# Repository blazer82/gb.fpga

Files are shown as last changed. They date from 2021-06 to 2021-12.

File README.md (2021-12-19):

[](https://github.com/blazer82/gb.fpga/actions?workflow=verilator-lint)

# FPGAMB0 - FPGA-based Handheld Console

This repository contains the PCB design files as well as the HDL sources for an FPGA-based handheld console that plays games from Gameboy cartridges.

## Demo (GIF)

Demo

## Testbenches

Testbench files can be run and analyzed using _iverilog_ and _GTKWave_:

```
iverilog -o main src/hdl/ascii_encoder_tb.v && vvp main -lxt2 && open dump.lx2
```

[verilator-lint-badge]: https://github.com/blazer82/gb.fpga/workflows/verilator-lint/badge.svg

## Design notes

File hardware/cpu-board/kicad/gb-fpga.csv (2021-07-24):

Cartridge-32pin | J
Pin | Name | Type | Side | Unit | Style | Hidden
1 | VCC | pwr | left | 1
2 | CLK | in | left | 1
3 | ~WR~ | in | left | 1
4 | ~RD~ | in | left | 1
5 | ~CS~ | in | left | 1
6 | A0 | in | left | 1
7 | A1 | in | left | 1
8 | A2 | in | left | 1
9 | A3 | in | left | 1
10 | A4 | in | left | 1
11 | A5 | in | left | 1
12 | A6 | in | left | 1
13 | A7 | in | left | 1
14 | A8 | in | left | 1
15 | A9 | in | left | 1
16 | A10 | in | left | 1
17 | A11 | in | left | 1
18 | A12 | in | left | 1
19 | A13 | in | left | 1
20 | A14 | in | left | 1
21 | A15 | in | left | 1
22 | D0 | passive | left | 1
23 | D1 | passive | left | 1
24 | D2 | passive | left | 1
25 | D3 | passive | left | 1
26 | D4 | passive | left | 1
27 | D5 | passive | left | 1
28 | D6 | passive | left | 1
29 | D7 | passive | left | 1
30 | ~RST~ | in | left | 1
31 | NC | NC | left | 1
32 | GND | pwr | left | 1
R_POT_Dual | RV
Pin | Name | Type | Side | Unit | Style | Hidden
1 | 1 | passive | left | 1
2 | 2 | passive | left | 1
3 | 3 | passive | top | 1
4 | 4 | passive | top | 1
5 | 5 | passive | right | 1
5 | 5 | passive | right | 1
Switch | SW
Pin | Name | Type | Side | Unit | Style | Hidden
1 | ~ | passive | right | 1
2 | ~ | passive | left | 1
3 | ~ | passive | right | 1
4 | GND | pwr | left | 1
TXS0108E | U
Pin | Name | Type | Side | Unit | Style | Hidden
1 | A1 | bidir | left | 1
2 | VCCA | pwr | left | 1
3 | A2 | bidir | left | 1
4 | A3 | bidir | left | 1
5 | A4 | bidir | left | 1
6 | A5 | bidir | left | 1
7 | A6 | bidir | left | 1
8 | A7 | bidir | left | 1
9 | A8 | bidir | left | 1
10 | OE | in | left | 1
11 | GND | pwr | right | 1
12 | B8 | bidir | right | 1
13 | B7 | bidir | right | 1
14 | B6 | bidir | right | 1
15 | B5 | bidir | right | 1
16 | B4 | bidir | right | 1
17 | B3 | bidir | right | 1
18 | B2 | bidir | right | 1
19 | VCCB | pwr | right | 1
20 | B1 | bidir | right | 1
xc7s25ftgb196 | U
Pin | Name | Type | Side | Unit | Style | Hidden
A7 | TCK_0 | in | right | 1
A8 | CCLK_0 | in | left | 1
A10 | IO_L3N_T0_DQS_EMCCLK_14 | bidir | right | 1
B10 | IO_L3P_T0_DQS_PUDC_B_14 | bidir | right | 1
B11 | IO_L1P_T0_D00_MOSI_14 | bidir | right | 1
B12 | IO_L1N_T0_D01_DIN_14 | bidir | right | 1
C10 | IO_L2N_T0_D03_14 | bidir | right | 1
C11 | IO_L6P_T0_FCS_B_14 | bidir | right | 1
D10 | IO_L2P_T0_D02_14 | bidir | right | 1
G7 | VREFN_0 | in | left | 1
G8 | VP_0 | in | left | 1
H7 | VN_0 | in | left | 1
H8 | VREFP_0 | in | left | 1
J7 | DXN_0 | passive | left | 1
J8 | DXP_0 | passive | left | 1
L7 | PROGRAM_B_0 | in | left | 1
M6 | TMS_0 | in | right | 1
M7 | M0_0 | in | left | 1
M8 | M1_0 | in | left | 1
M9 | M2_0 | in | left | 1
N7 | CFGBVS_0 | in | left | 1
P6 | TDO_0 | out | right | 1
P7 | TDI_0 | in | right | 1
P8 | INIT_B_0 | in | left | 1
P9 | DONE_0 | out | left | 1
A12 | IO_L4P_T0_D04_14 | bidir | left | 2
A13 | IO_L4N_T0_D05_14 | bidir | left | 2
B13 | IO_L5P_T0_D06_14 | bidir | left | 2
B14 | IO_L5N_T0_D07_14 | bidir | left | 2
C12 | IO_L6N_T0_D08_VREF_14 | bidir | left | 2
C14 | IO_L11N_T1_SRCC_14 | bidir | left | 2
D12 | IO_L8P_T1_D11_14 | bidir | left | 2
D13 | IO_L8N_T1_D12_14 | bidir | left | 2
D14 | IO_L11P_T1_SRCC_14 | bidir | left | 2
E11 | IO_0_14 | bidir | left | 2
E12 | IO_L7N_T1_D10_14 | bidir | left | 2
E13 | IO_L10N_T1_D15_14 | bidir | left | 2
F11 | IO_L12N_T1_MRCC_14 | bidir | left | 2
F12 | IO_L7P_T1_D09_14 | bidir | left | 2
F13 | IO_L10P_T1_D14_14 | bidir | left | 2
F14 | IO_L9N_T1_DQS_D13_14 | bidir | left | 2
G11 | IO_L12P_T1_MRCC_14 | bidir | left | 2
G14 | IO_L9P_T1_DQS_14 | bidir | left | 2
H11 | IO_L13P_T2_MRCC_14 | bidir | left | 2
H12 | IO_L13N_T2_MRCC_14 | bidir | left | 2
H13 | IO_L14P_T2_SRCC_14 | bidir | left | 2
H14 | IO_L14N_T2_SRCC_14 | bidir | left | 2
J11 | IO_L17P_T2_D30_14 | bidir | left | 2
J12 | IO_L17N_T2_D29_14 | bidir | left | 2
J13 | IO_L18P_T2_D28_14 | bidir | left | 2
J14 | IO_L18N_T2_D27_14 | bidir | left | 2
K11 | IO_L19P_T3_D26_14 | bidir | left | 2
K12 | IO_L19N_T3_D25_VREF_14 | bidir | left | 2
L12 | IO_L16P_T2_CSI_B_14 | bidir | left | 2
L13 | IO_L16N_T2_D31_14 | bidir | left | 2
L14 | IO_L15N_T2_DQS_DOUT_CSO_B_14 | bidir | left | 2
M10 | IO_25_14 | bidir | left | 2
M11 | IO_L20P_T3_D24_14 | bidir | left | 2
M12 | IO_L20N_T3_D23_14 | bidir | left | 2
M13 | IO_L15P_T2_DQS_RDWR_B_14 | bidir | left | 2
M14 | IO_L21N_T3_DQS_D22_14 | bidir | left | 2
N10 | IO_L23P_T3_D19_14 | bidir | left | 2
N11 | IO_L23N_T3_D18_14 | bidir | left | 2
N14 | IO_L21P_T3_DQS_14 | bidir | left | 2
P10 | IO_L24P_T3_D17_14 | bidir | left | 2
P11 | IO_L24N_T3_D16_14 | bidir | left | 2
P12 | IO_L22P_T3_D21_14 | bidir | left | 2
P13 | IO_L22N_T3_D20_14 | bidir | left | 2
A2 | IO_L3N_T0_DQS_34 | bidir | left | 3
A3 | IO_L2N_T0_34 | bidir | left | 3
A4 | IO_L2P_T0_34 | bidir | left | 3
A5 | IO_L4N_T0_34 | bidir | left | 3
B1 | IO_L5N_T0_34 | bidir | left | 3
B2 | IO_L5P_T0_34 | bidir | left | 3
B3 | IO_L3P_T0_DQS_34 | bidir | left | 3
B5 | IO_L4P_T0_34 | bidir | left | 3
B6 | IO_0_34 | bidir | left | 3
C1 | IO_L11N_T1_SRCC_34 | bidir | left | 3
C3 | IO_L1N_T0_34 | bidir | left | 3
C4 | IO_L6N_T0_VREF_34 | bidir | left | 3
C5 | IO_L6P_T0_34 | bidir | left | 3
D1 | IO_L11P_T1_SRCC_34 | bidir | left | 3
D2 | IO_L10N_T1_34 | bidir | left | 3
D3 | IO_L1P_T0_34 | bidir | left | 3
D4 | IO_L7N_T1_34 | bidir | left | 3
E2 | IO_L10P_T1_34 | bidir | left | 3
E4 | IO_L7P_T1_34 | bidir | left | 3
F1 | IO_L9N_T1_DQS_34 | bidir | left | 3
F2 | IO_L8N_T1_34 | bidir | left | 3
F3 | IO_L8P_T1_34 | bidir | left | 3
F4 | IO_L12N_T1_MRCC_34 | bidir | left | 3
G1 | IO_L9P_T1_DQS_34 | bidir | left | 3
G4 | IO_L12P_T1_MRCC_34 | bidir | left | 3
H1 | IO_L14N_T2_SRCC_34 | bidir | left | 3
H2 | IO_L14P_T2_SRCC_34 | bidir | left | 3
H3 | IO_L13N_T2_MRCC_34 | bidir | left | 3
H4 | IO_L13P_T2_MRCC_34 | bidir | left | 3
J1 | IO_L15N_T2_DQS_34 | bidir | left | 3
J2 | IO_L15P_T2_DQS_34 | bidir | left | 3
J3 | IO_L17N_T2_34 | bidir | left | 3
J4 | IO_L17P_T2_34 | bidir | left | 3
K3 | IO_L16N_T2_34 | bidir | left | 3
K4 | IO_L16P_T2_34 | bidir | left | 3
L1 | IO_L18N_T2_34 | bidir | left | 3
L2 | IO_L22N_T3_34 | bidir | left | 3
L3 | IO_L22P_T3_34 | bidir | left | 3
L5 | IO_25_34 | bidir | left | 3
M1 | IO_L18P_T2_34 | bidir | left | 3
M2 | IO_L19N_T3_VREF_34 | bidir | left | 3
M3 | IO_L19P_T3_34 | bidir | left | 3
M4 | IO_L23N_T3_34 | bidir | left | 3
M5 | IO_L23P_T3_34 | bidir | left | 3
N1 | IO_L20N_T3_34 | bidir | left | 3
N4 | IO_L24N_T3_34 | bidir | left | 3
P2 | IO_L20P_T3_34 | bidir | left | 3
P3 | IO_L21N_T3_DQS_34 | bidir | left | 3
P4 | IO_L21P_T3_DQS_34 | bidir | left | 3
P5 | IO_L24P_T3_34 | bidir | left | 3
A1 | GND[50] | pwr | right | 4
A6 | GND[50] | pwr | right | 4
A9 | GND[50] | pwr | right | 4
A11 | GND[50] | pwr | right | 4
A14 | GND[50] | pwr | right | 4
B4 | GND[50] | pwr | right | 4
B7 | GND[50] | pwr | right | 4
B8 | VCCBATT_0 | pwr | left | 4
B9 | GND[50] | pwr | right | 4
C2 | GND[50] | pwr | right | 4
C6 | GND[50] | pwr | right | 4
C7 | GND[50] | pwr | right | 4
C8 | GND[50] | pwr | right | 4
C9 | GND[50] | pwr | right | 4
C13 | GND[50] | pwr | right | 4
D5 | GND[50] | pwr | right | 4
D6 | VCCINT[10] | pwr | left | 4
D7 | GND[50] | pwr | right | 4
D8 | VCCINT[10] | pwr | left | 4
D9 | GND[50] | pwr | right | 4
D11 | GND[50] | pwr | right | 4
E1 | GND[50] | pwr | right | 4
E3 | GND[50] | pwr | right | 4
E5 | VCCBRAM[3] | pwr | left | 4
E6 | GND[50] | pwr | right | 4
E7 | VCCINT[10] | pwr | left | 4
E8 | GND[50] | pwr | right | 4
E9 | VCCINT[10] | pwr | left | 4
E10 | GND[50] | pwr | right | 4
E14 | GND[50] | pwr | right | 4
F5 | GND[50] | pwr | right | 4
F6 | VCCINT[10] | pwr | left | 4
F7 | GNDADC_0 | pwr | right | 4
F8 | VCCADC_0 | pwr | left | 4
F9 | GND[50] | pwr | right | 4
F10 | VCCAUX[4] | pwr | left | 4
G2 | VCCO_34[3] | pwr | left | 4
G3 | GND[50] | pwr | right | 4
G5 | VCCBRAM[3] | pwr | left | 4
G6 | GND[50] | pwr | right | 4
G9 | VCCINT[10] | pwr | left | 4
G10 | GND[50] | pwr | right | 4
G12 | GND[50] | pwr | right | 4
G13 | VCCO_14[3] | pwr | left | 4
H5 | GND[50] | pwr | right | 4
H6 | VCCINT[10] | pwr | left | 4
H9 | GND[50] | pwr | right | 4
H10 | VCCAUX[4] | pwr | left | 4
J5 | VCCBRAM[3] | pwr | left | 4
J6 | GND[50] | pwr | right | 4
J9 | VCCINT[10] | pwr | left | 4
J10 | GND[50] | pwr | right | 4
K1 | GND[50] | pwr | right | 4
K2 | VCCO_34[3] | pwr | left | 4
K5 | GND[50] | pwr | right | 4
K6 | VCCINT[10] | pwr | left | 4
K7 | GND[50] | pwr | right | 4
K8 | VCCINT[10] | pwr | left | 4
K9 | GND[50] | pwr | right | 4
K10 | VCCAUX[4] | pwr | left | 4
K13 | VCCO_14[3] | pwr | left | 4
K14 | GND[50] | pwr | right | 4
L4 | GND[50] | pwr | right | 4
L6 | GND[50] | pwr | right | 4
L8 | GND[50] | pwr | right | 4
L9 | VCCAUX[4] | pwr | left | 4
L10 | GND[50] | pwr | right | 4
L11 | GND[50] | pwr | right | 4
N2 | VCCO_34[3] | pwr | left | 4
N3 | GND[50] | pwr | right | 4
N5 | GND[50] | pwr | right | 4
N6 | VCCO_0[2] | pwr | left | 4
N8 | VCCO_0[2] | pwr | left | 4
N9 | GND[50] | pwr | right | 4
N12 | GND[50] | pwr | right | 4
N13 | VCCO_14[3] | pwr | left | 4
P1 | GND[50] | pwr | right | 4
P14 | GND[50] | pwr | right | 4

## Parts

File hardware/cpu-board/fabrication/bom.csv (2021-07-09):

Designator | Value | Package/Footprint | Mfg Part # | Qty
C1, C50, C51, C52, C53, C54, C55, C56, C57, C59, C61, C62, C63, C64, C65, C66, C67, C68 | 100nF | 0402 | CL05B104KO5NNNC | 18
C1 | 100nF | 0402 | CL05B104KO5NNNC | 1
C50 | 100nF | 0402 | CL05B104KO5NNNC | 1
C51 | 100nF | 0402 | CL05B104KO5NNNC | 1
C52 | 100nF | 0402 | CL05B104KO5NNNC | 1
C53 | 100nF | 0402 | CL05B104KO5NNNC | 1
C54 | 100nF | 0402 | CL05B104KO5NNNC | 1
C55 | 100nF | 0402 | CL05B104KO5NNNC | 1
C56 | 100nF | 0402 | CL05B104KO5NNNC | 1
C57 | 100nF | 0402 | CL05B104KO5NNNC | 1
C59 | 100nF | 0402 | CL05B104KO5NNNC | 1
C61 | 100nF | 0402 | CL05B104KO5NNNC | 1
C62 | 100nF | 0402 | CL05B104KO5NNNC | 1
C63 | 100nF | 0402 | CL05B104KO5NNNC | 1
C64 | 100nF | 0402 | CL05B104KO5NNNC | 1
C65 | 100nF | 0402 | CL05B104KO5NNNC | 1
C66 | 100nF | 0402 | CL05B104KO5NNNC | 1
C67 | 100nF | 0402 | CL05B104KO5NNNC | 1
C68 | 100nF | 0402 | CL05B104KO5NNNC | 1
C2 | 10nF | 0402 | CL05B103KB5NNNC | 1
C3 | 470nF | 0402 | CL05A474KP5NNNC | 1
C4, C6, C8 | 20pF | 0402 | CL05C220JB5NNNC | 3
C5, C11 | 22µF | 0402 | GRM155R60J226ME11D | 2
C7, C9, C10 | 10µF | 0402 | CL05A106MP5NUNC | 3
C12 | 1µF | 0402 | CL05A105KO5NNNC | 1
C14, C18 | 47µF | 0603 | CL10A476MQ8QRNC | 2
C21, C27, C34, C41 | 100µF | 1206 | GRM31CR61A107ME05L | 4
C15, C19, C22, C23, C28, C29, C35, C36, C42, C43 | 4.7µF | 0201 | GRM035R60J475ME15D | 10
C16, C17, C20, C24, C25, C26, C30, C31, C32, C33, C37, C38, C39, C40, C44, C45, C46, C47 | 470nF | 0201 | GRM033R60J474KE90D | 18
C48, C49 | 4.7nF | 0402 | CL05B472KA5NNNC | 2
C13, C58, C60 | 4.7µF | 0402 | CL05A475KP5NRNC | 3
D1 | DONE | 0402 | NCD0402G1 | 1
D2 | PMEG2020EJ | SOD-323 | PMEG2020EJF | 1
D3 | CHRG | 0402 | NCD0402B1 | 1
J1 | USB_C_Receptacle_USB2.0 |  | U262-161N-4BVC11 | 1
J5 | Conn_02x25_Counter_Clockwise |  | FH12-50S-0.5SH(55) | 1
L1 | 1.5µH | 0402 | SDFL1005Q1R5KTF | 1
L2, L4 | 3.3µH | 0402 | SDFL1005Q3R3KTF | 2
L3 | 2.2µH | 0402 | SDFL1005Q2R2KTF | 1
L5 | 10µH | 0603 | SDFL1608S100KTF | 1
L6, L7 | 600R/0.5A | 0402 | BLM15AX601SN1D | 2
Q1 | MBT3904DW1 | SOT-363 | MBT3904DW1T1H | 1
R1, R5, R6, R7, R16, R17 | 4.7k | 0402 | RC0402JR-074K7L | 6
R2, R3 | 1.8k | 0402 | RC0402JR-071K8L | 2
R4, R15, R31, R35, R36 | 1k | 0402 | RC0402JR-071KL | 5
R8, R9, R32 | 200Ω | 0402 | AC0402JR-07200RL | 3
R10, R11, R12, R13, R26, R28 | 10k | 0402 | RC0402JR-0710KL | 6
R14 | 12k | 0402 | RC0402FR-0712KL | 1
R18, R27 | 3k | 0402 | RC0402FR-073KL | 2
R19 | 2k | 0402 | RC0402FR-072KL | 1
R20, R29, R30 | 30k | 0402 | AF0402FR-0730KL | 3
R21, R23 | 120k | 0402 | RC0402FR-07120KL | 2
R22 | 150k | 0402 | RC0402FR-07150KL | 1
R24, R34 | 180k | 0402 | RC0402FR-07180KL | 2
R25 | 57.6k | 0402 | RC0402FR-0757K6L | 1
R33 | 953k | 0402 | RC0402FR-07953KL | 1
U1 | xc7s25ftgb196 |  | XC7S25-1FTGB196C | 1
U2 | MX25R3235FZBxx1 | USON-8 | MX25L3233FZBI-08Q | 1
U3 | FT2232HQ | QFN-64 | FT2232HQ-REEL | 1
U4 | LTC3555 | QFN-28 | LTC3555IUFD-1#PBF | 1
U5 | TLV61046ADB | SOT-23-6 | TLV61046ADBVR | 1
U6, U7, U8, U9 | TXS0108E | TSSOP-20 | TXS0108EPWR | 4
X1 | SG-8002JA |  | CB3LV-3C-12M000000 | 1

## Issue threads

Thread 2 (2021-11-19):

Issue with the 12V rail

blazer82, 2021-11-19:
The 12V rail seems to be underpowered to provide proper power to the audio/video system. This is very noticeable when turning up the audio volume.

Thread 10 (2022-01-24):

Interest in PCB Design / Layout

32teeth, 2022-01-24:
# Hi
> Introduction

I created the Gameboy Pocket versions for
* [Gaboze Pocaio](https://github.com/Gaboze-Pocaio/Round-2) (Raspberry Pi)
* [Retro ESP32](https://github.com/retro-esp32/RetroESP32)

I've been looking at the next Gameboy Pocket emulation, and came across your FPGA project

blazer82, 2022-02-11:
Hi and sorry for the late reply. The PCB Design files are in this repository inside the hardware folder.

32teeth, 2022-06-24:
Hardware is [here](https://github.com/retro-esp32/RetroESP32-Hardware)

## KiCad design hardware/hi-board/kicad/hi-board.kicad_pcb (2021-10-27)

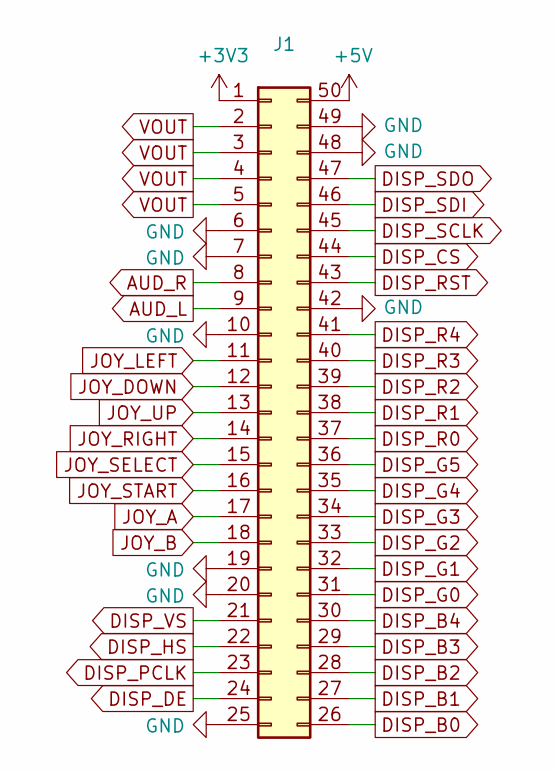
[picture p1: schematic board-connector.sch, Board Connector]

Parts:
J1: Conn_02x25_Counter_Clockwise; Hirose_FH12-50S-0.5SH_1x50-1MP_P0.50mm_Horizontal

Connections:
unnamed: J1.2, J1.3, J1.4, J1.5
unnamed: J1.6, J1.7, J1.10, J1.19, J1.20, J1.25, J1.42, J1.48, J1.49

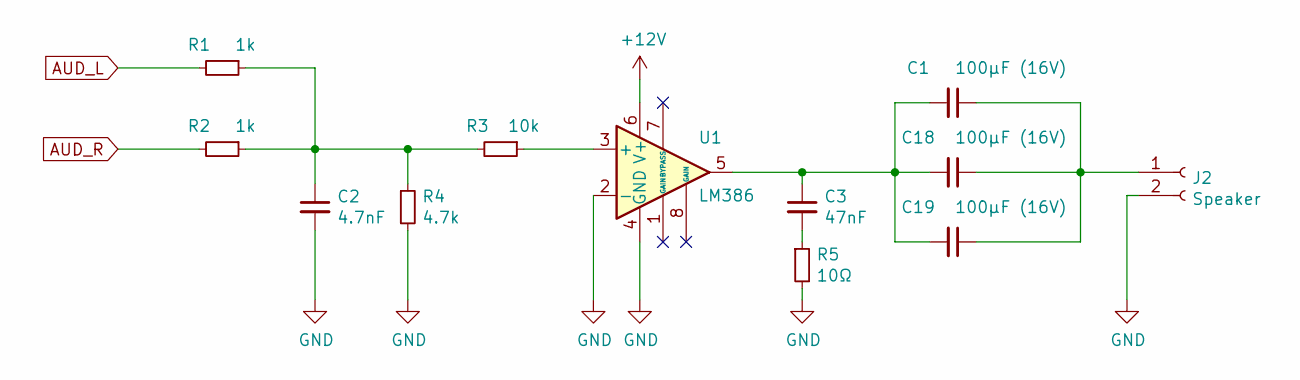
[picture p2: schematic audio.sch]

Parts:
C1, C18, C19: 100µF (16V); C_1210_3225Metric
C2: 4.7nF; C_0603_1608Metric
C3: 47nF; C_0603_1608Metric
J2: Speaker; PinHeader_1x02_P2.54mm_Vertical
R1, R2: 1k; R_0603_1608Metric
R3: 10k; R_0603_1608Metric
R4: 4.7k; R_0603_1608Metric
R5: 10Ω; R_0603_1608Metric
U1: LM386; VSSOP-8_3.0x3.0mm_P0.65mm

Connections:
+12V: U1.6 (V+); also elsewhere on the board
AUD_L: R1.2; also elsewhere on the board
AUD_R: R2.2; also elsewhere on the board
GND: C2.2, J2.2, R4.2, R5.2, U1.2 (-), U1.4 (GND); also elsewhere on the board
unnamed: C1.1, C18.1, C19.1, J2.1
unnamed: C1.2, C3.1, C18.2, C19.2, U1.5
unnamed: C2.1, R1.1, R2.1, R3.2, R4.1
unnamed: C3.2, R5.1
unnamed: R3.1, U1.3 (+)

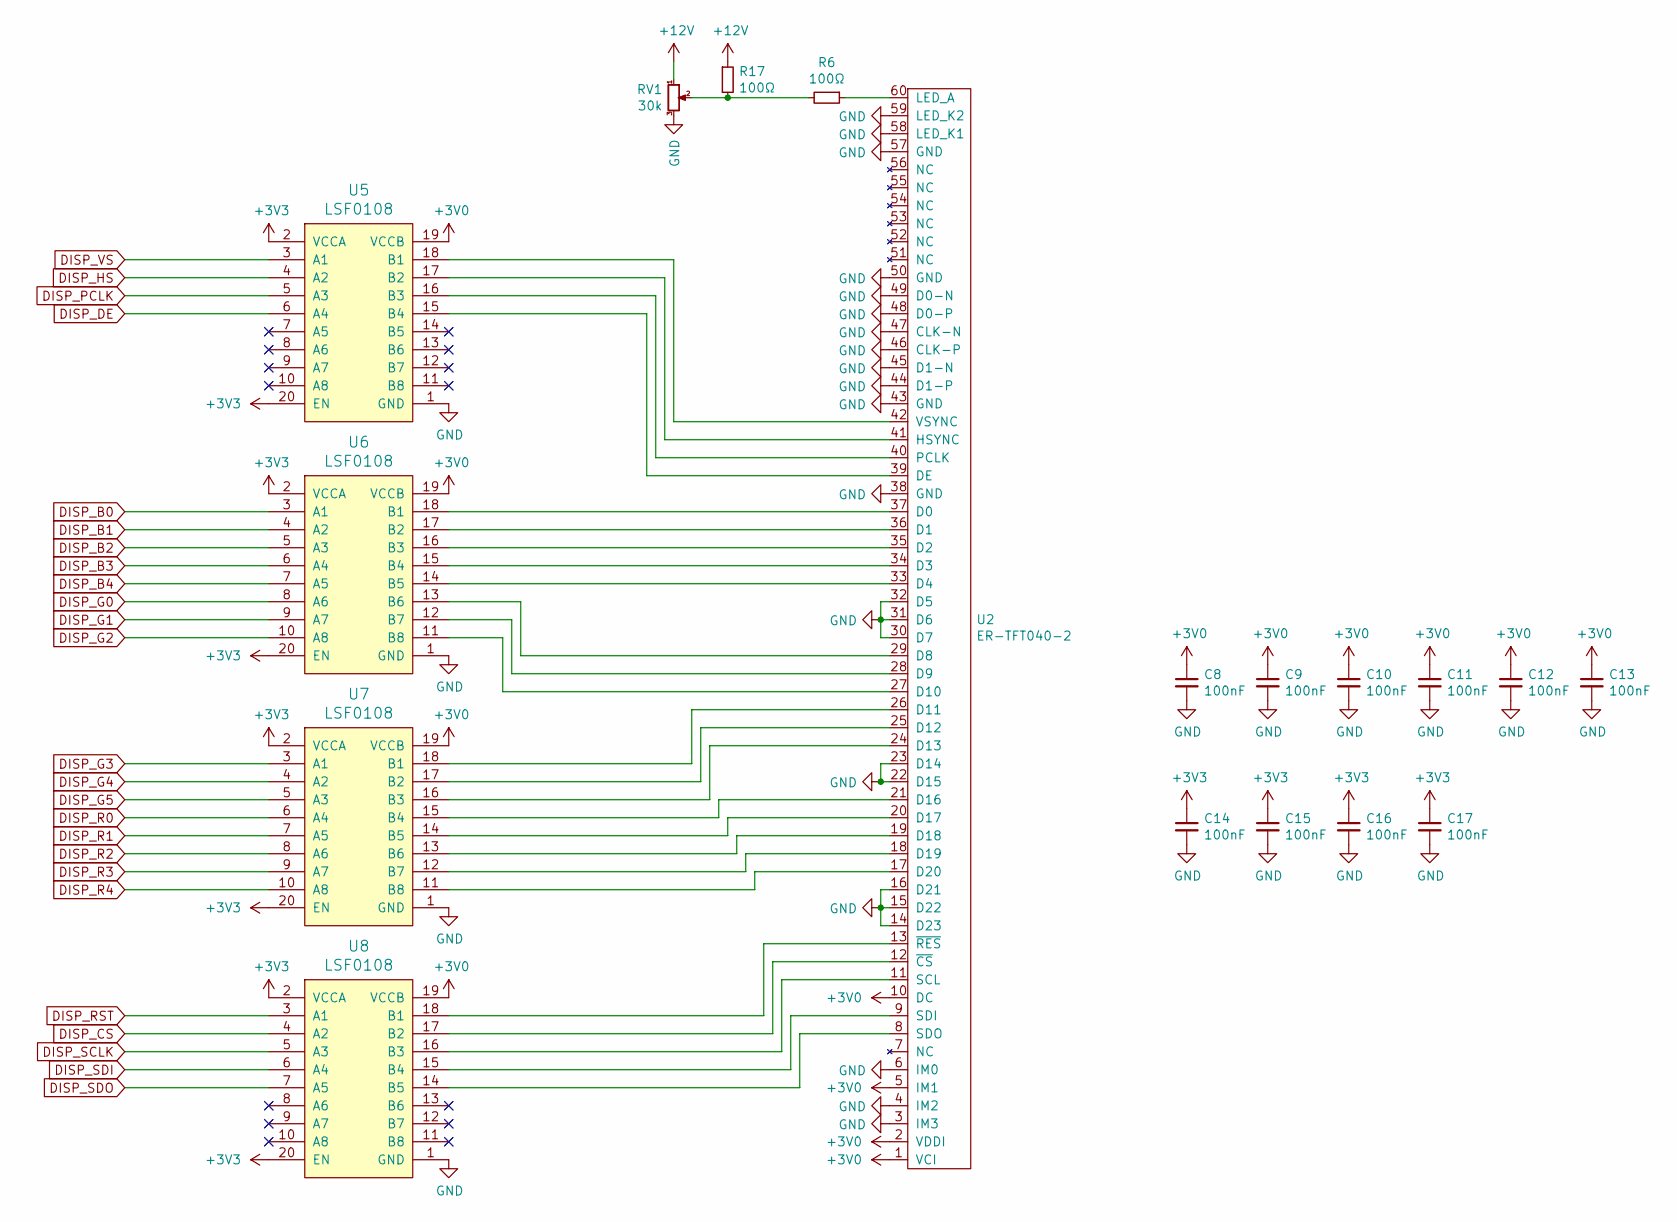
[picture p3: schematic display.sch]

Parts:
C8, C9, C10, C11, C12, C13, C14, C15, C16, C17: 100nF; C_0603_1608Metric
R6, R17: 100Ω; R_0603_1608Metric
RV1: 30k; Dual_Pot
U2: ER-TFT040-2; HRS_FH28-60S-0.5SH(05)
U5, U6, U7, U8: LSF0108; TSSOP-20_4.4x6.5mm_P0.65mm

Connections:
+3V0: C8.1, C9.1, C10.1, C11.1, C12.1, C13.1, U2.1 (VCI), U2.2 (VDDI), U2.5 (IM1), U2.10 (DC), U5.19 (VCCB), U6.19 (VCCB), U7.19 (VCCB), U8.19 (VCCB); also elsewhere on the board
+3V3: C14.1, C15.1, C16.1, C17.1, U5.2 (VCCA), U5.20 (EN), U6.2 (VCCA), U6.20 (EN), U7.2 (VCCA), U7.20 (EN), U8.2 (VCCA), U8.20 (EN); also elsewhere on the board
+12V: R17.1, RV1.1; also elsewhere on the board
DISP_B0: U6.3 (A1); also elsewhere on the board
DISP_B1: U6.4 (A2); also elsewhere on the board
DISP_B2: U6.5 (A3); also elsewhere on the board
DISP_B3: U6.6 (A4); also elsewhere on the board
DISP_B4: U6.7 (A5); also elsewhere on the board
DISP_CS: U8.4 (A2); also elsewhere on the board
DISP_DE: U5.6 (A4); also elsewhere on the board
DISP_G0: U6.8 (A6); also elsewhere on the board
DISP_G1: U6.9 (A7); also elsewhere on the board
DISP_G2: U6.10 (A8); also elsewhere on the board
DISP_G3: U7.3 (A1); also elsewhere on the board
DISP_G4: U7.4 (A2); also elsewhere on the board
DISP_G5: U7.5 (A3); also elsewhere on the board
DISP_HS: U5.4 (A2); also elsewhere on the board
DISP_PCLK: U5.5 (A3); also elsewhere on the board
DISP_R0: U7.6 (A4); also elsewhere on the board
DISP_R1: U7.7 (A5); also elsewhere on the board
DISP_R2: U7.8 (A6); also elsewhere on the board
DISP_R3: U7.9 (A7); also elsewhere on the board
DISP_R4: U7.10 (A8); also elsewhere on the board
DISP_RST: U8.3 (A1); also elsewhere on the board
DISP_SCLK: U8.5 (A3); also elsewhere on the board
DISP_SDI: U8.6 (A4); also elsewhere on the board
DISP_SDO: U8.7 (A5); also elsewhere on the board
DISP_VS: U5.3 (A1); also elsewhere on the board
GND: C8.2, C9.2, C10.2, C11.2, C12.2, C13.2, C14.2, C15.2, C16.2, C17.2, RV1.3, U2.3 (IM3), U2.4 (IM2), U2.6 (IM0), U2.14 (D23), U2.15 (D22), U2.16 (D21), U2.22 (D15), U2.23 (D14), U2.30 (D7), U2.31 (D6), U2.32 (D5), U2.38 (GND), U2.43 (GND), U2.44 (D1-P), U2.45 (D1-N), U2.46 (CLK-P), U2.47 (CLK-N), U2.48 (D0-P), U2.49 (D0-N), U2.50 (GND), U2.57 (GND), U2.58 (LED_K1), U2.59 (LED_K2), U5.1 (GND), U6.1 (GND), U7.1 (GND), U8.1 (GND); also elsewhere on the board
unnamed 48: R6.1, U2.60 (LED_A); also elsewhere on the board
unnamed: R6.2, R17.2, RV1.2
unnamed 55: U2.8 (SDO), U8.14 (B5); also elsewhere on the board
unnamed 56: U2.9 (SDI), U8.15 (B4); also elsewhere on the board
unnamed 57: U2.11 (SCL), U8.16 (B3); also elsewhere on the board
unnamed 58: U2.12 (~CS), U8.17 (B2); also elsewhere on the board
unnamed 59: U2.13 (~RES), U8.18 (B1); also elsewhere on the board
unnamed 60: U2.17 (D20), U7.11 (B8); also elsewhere on the board
unnamed 61: U2.18 (D19), U7.12 (B7); also elsewhere on the board
unnamed 62: U2.19 (D18), U7.13 (B6); also elsewhere on the board
unnamed 63: U2.20 (D17), U7.14 (B5); also elsewhere on the board
unnamed 64: U2.21 (D16), U7.15 (B4); also elsewhere on the board
unnamed 65: U2.24 (D13), U7.16 (B3); also elsewhere on the board
unnamed 66: U2.25 (D12), U7.17 (B2); also elsewhere on the board
unnamed 67: U2.26 (D11), U7.18 (B1); also elsewhere on the board
unnamed 68: U2.27 (D10), U6.11 (B8); also elsewhere on the board
unnamed 69: U2.28 (D9), U6.12 (B7); also elsewhere on the board
unnamed 70: U2.29 (D8), U6.13 (B6); also elsewhere on the board
unnamed 71: U2.33 (D4), U6.14 (B5); also elsewhere on the board
unnamed 72: U2.34 (D3), U6.15 (B4); also elsewhere on the board
unnamed 73: U2.35 (D2), U6.16 (B3); also elsewhere on the board
unnamed 74: U2.36 (D1), U6.17 (B2); also elsewhere on the board
unnamed 75: U2.37 (D0), U6.18 (B1); also elsewhere on the board
unnamed 76: U2.39 (DE), U5.15 (B4); also elsewhere on the board
unnamed 77: U2.40 (PCLK), U5.16 (B3); also elsewhere on the board
unnamed 78: U2.41 (HSYNC), U5.17 (B2); also elsewhere on the board
unnamed 79: U2.42 (VSYNC), U5.18 (B1); also elsewhere on the board

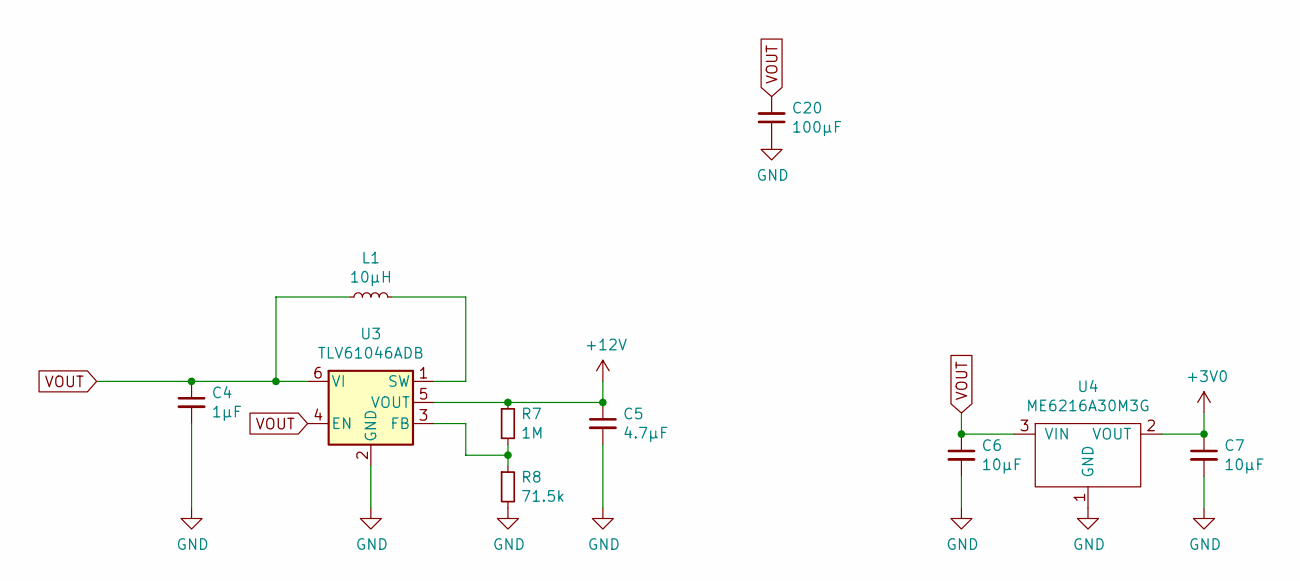
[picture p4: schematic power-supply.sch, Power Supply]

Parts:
C4: 1µF; C_0603_1608Metric
C5: 4.7µF; C_0603_1608Metric
C6, C7: 10µF; C_0603_1608Metric
C20: 100µF; C_1210_3225Metric
L1: 10µH; L_0603_1608Metric
R7: 1M; R_0603_1608Metric
R8: 71.5k; R_0603_1608Metric
U3: TLV61046ADB; SOT-23-6
U4: ME6216A30M3G; SOT-23

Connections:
+3V0: C7.1, U4.2 (VOUT); also elsewhere on the board
+12V: C5.1, R7.1, U3.5 (VOUT); also elsewhere on the board
GND: C4.2, C5.2, C6.2, C7.2, C20.1, R8.2, U3.2 (GND), U4.1 (GND); also elsewhere on the board
unnamed: L1.2, U3.1 (SW)
unnamed: R7.2, R8.1, U3.3 (FB)
VOUT: C4.1, C6.1, C20.2, L1.1, U3.4 (EN), U3.6 (VI), U4.3 (VIN); also elsewhere on the board

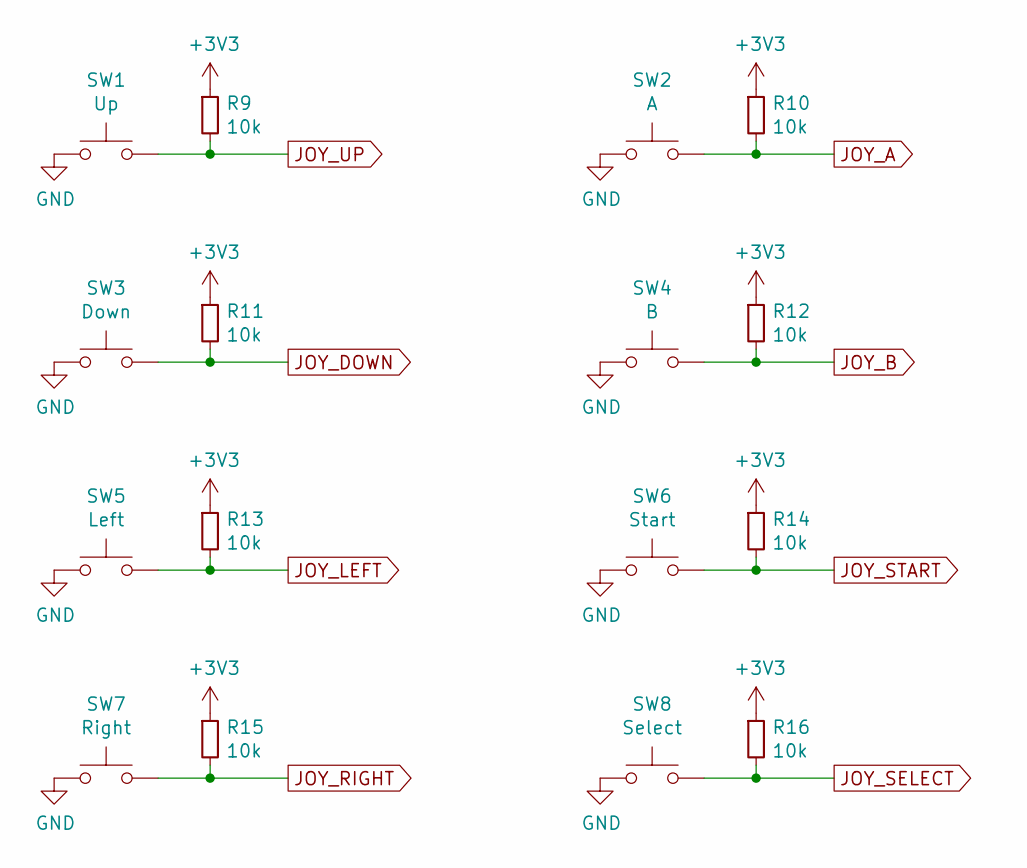
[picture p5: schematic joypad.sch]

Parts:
R9, R10, R11, R12, R13, R14, R15, R16: 10k; R_0603_1608Metric
SW1: Up; Rubber_Round
SW2: A; Rubber_Round
SW3: Down; Rubber_Round
SW4: B; Rubber_Round
SW5: Left; Rubber_Round
SW6: Start; Rubber_Square
SW7: Right; Rubber_Round
SW8: Select; Rubber_Square

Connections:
+3V3: R9.1, R10.1, R11.1, R12.1, R13.1, R14.1, R15.1, R16.1; also elsewhere on the board
GND: SW1.1, SW2.1, SW3.1, SW4.1, SW5.1, SW6.1, SW7.1, SW8.1; also elsewhere on the board
JOY_A: R10.2, SW2.2; also elsewhere on the board
JOY_B: R12.2, SW4.2; also elsewhere on the board
JOY_DOWN: R11.2, SW3.2; also elsewhere on the board
JOY_LEFT: R13.2, SW5.2; also elsewhere on the board
JOY_RIGHT: R15.2, SW7.2; also elsewhere on the board
JOY_SELECT: R16.2, SW8.2; also elsewhere on the board
JOY_START: R14.2, SW6.2; also elsewhere on the board
JOY_UP: R9.2, SW1.2; also elsewhere on the board

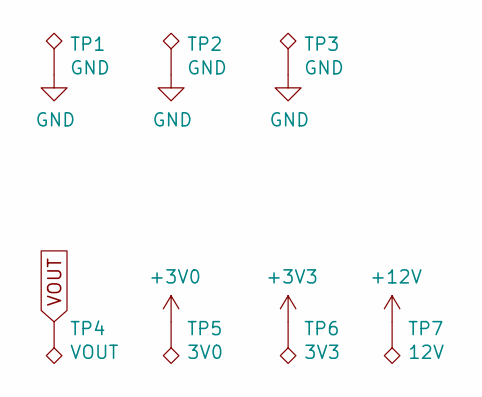
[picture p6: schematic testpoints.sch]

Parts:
TP1, TP2, TP3: GND; TestPoint_THTPad_1.5x1.5mm_Drill0.7mm
TP4: VOUT; TestPoint_THTPad_1.0x1.0mm_Drill0.5mm
TP5: 3V0; TestPoint_THTPad_1.0x1.0mm_Drill0.5mm
TP6: 3V3; TestPoint_THTPad_1.0x1.0mm_Drill0.5mm
TP7: 12V; TestPoint_THTPad_1.0x1.0mm_Drill0.5mm

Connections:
+3V0: TP5.1; also elsewhere on the board
+3V3: TP6.1; also elsewhere on the board
+12V: TP7.1; also elsewhere on the board
GND: TP1.1, TP2.1, TP3.1; also elsewhere on the board
VOUT: TP4.1; also elsewhere on the board

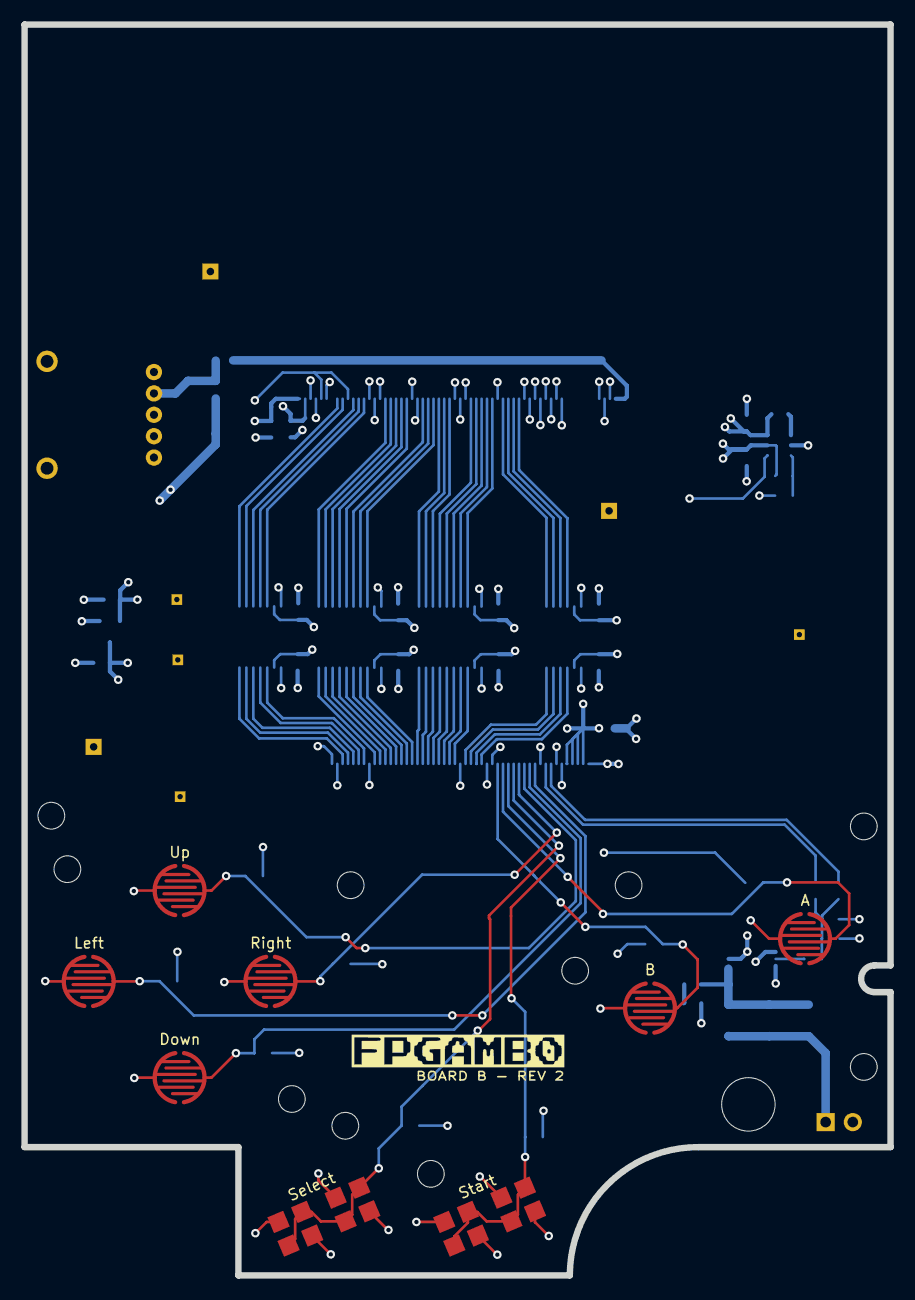
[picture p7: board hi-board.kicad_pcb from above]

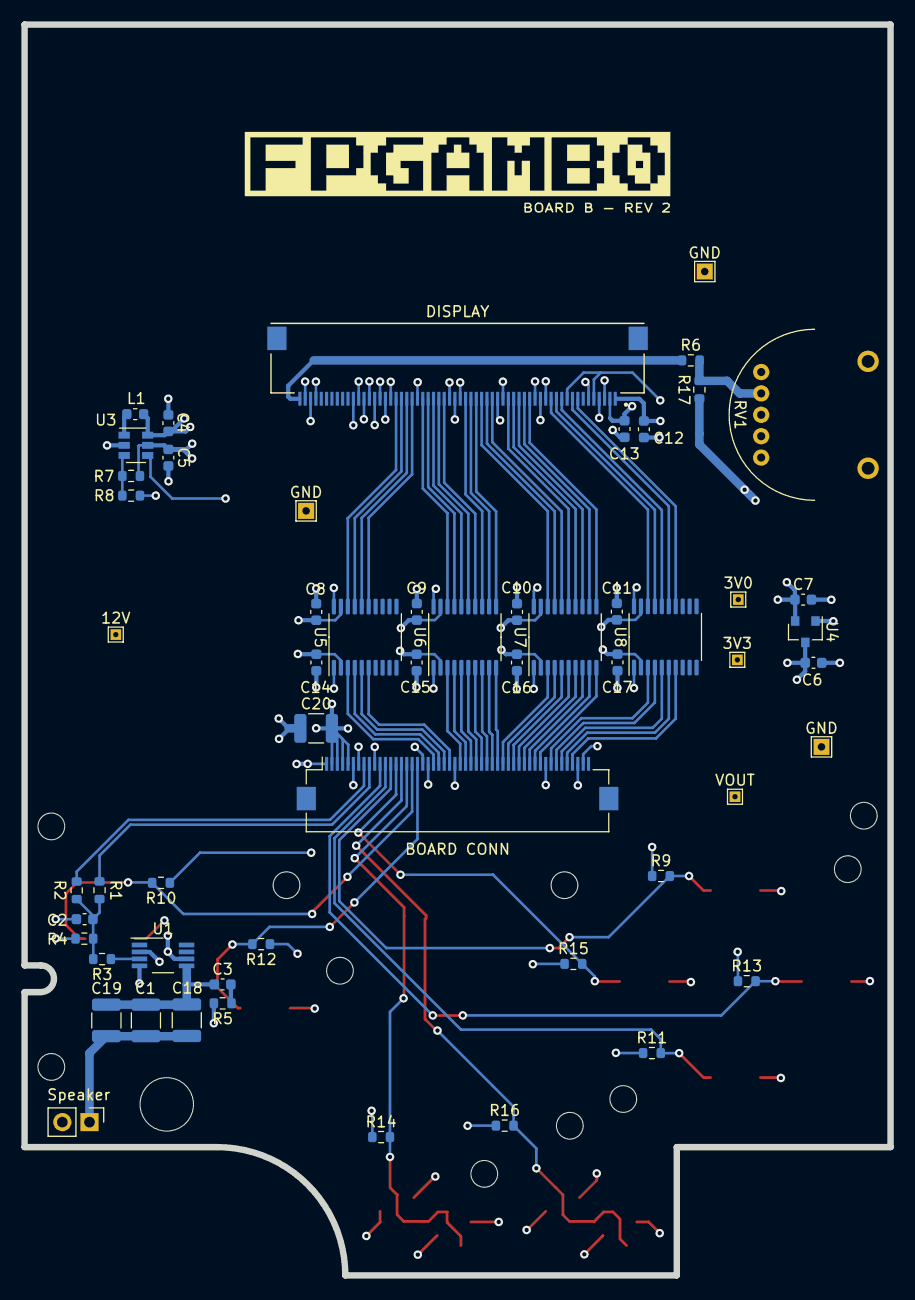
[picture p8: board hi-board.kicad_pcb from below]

Board: 4 copper layers, 81.0 x 117.0 mm, 64 parts (56 on the bottom side), 74 nets.

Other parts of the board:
BOARD CONN: Conn_02x25_Counter_Clockwise; Hirose_FH12-50S-0.5SH_1x50-1MP_P0.50mm_Horizontal
DISPLAY: ER-TFT040-2; HRS_FH28-60S-0.5SH(05)

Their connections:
+3V0: DISPLAY.1, DISPLAY.2, DISPLAY.5, DISPLAY.10; also elsewhere on the board
+3V3: BOARD CONN.1; also elsewhere on the board
AUD_L: BOARD CONN.9; also elsewhere on the board
AUD_R: BOARD CONN.8; also elsewhere on the board
DISP_B0: BOARD CONN.26; also elsewhere on the board
DISP_B1: BOARD CONN.27; also elsewhere on the board
DISP_B2: BOARD CONN.28; also elsewhere on the board
DISP_B3: BOARD CONN.29; also elsewhere on the board
DISP_B4: BOARD CONN.30; also elsewhere on the board
DISP_CS: BOARD CONN.44; also elsewhere on the board
DISP_DE: BOARD CONN.24; also elsewhere on the board
DISP_G0: BOARD CONN.31; also elsewhere on the board
DISP_G1: BOARD CONN.32; also elsewhere on the board
DISP_G2: BOARD CONN.33; also elsewhere on the board
DISP_G3: BOARD CONN.34; also elsewhere on the board
DISP_G4: BOARD CONN.35; also elsewhere on the board
DISP_G5: BOARD CONN.36; also elsewhere on the board
DISP_HS: BOARD CONN.22; also elsewhere on the board
DISP_PCLK: BOARD CONN.23; also elsewhere on the board
DISP_R0: BOARD CONN.37; also elsewhere on the board
DISP_R1: BOARD CONN.38; also elsewhere on the board
DISP_R2: BOARD CONN.39; also elsewhere on the board
DISP_R3: BOARD CONN.40; also elsewhere on the board
DISP_R4: BOARD CONN.41; also elsewhere on the board
DISP_RST: BOARD CONN.43; also elsewhere on the board
DISP_SCLK: BOARD CONN.45; also elsewhere on the board
DISP_SDI: BOARD CONN.46; also elsewhere on the board
DISP_SDO: BOARD CONN.47; also elsewhere on the board
DISP_VS: BOARD CONN.21; also elsewhere on the board
GND: BOARD CONN.6, BOARD CONN.7, BOARD CONN.10, BOARD CONN.19, BOARD CONN.20, BOARD CONN.25, BOARD CONN.42, BOARD CONN.48, BOARD CONN.49, DISPLAY.3, DISPLAY.4, DISPLAY.6, DISPLAY.14, DISPLAY.15, DISPLAY.16, DISPLAY.22, DISPLAY.23, DISPLAY.30, DISPLAY.31, DISPLAY.32, DISPLAY.38, DISPLAY.43, DISPLAY.44, DISPLAY.45, DISPLAY.46, DISPLAY.47, DISPLAY.48, DISPLAY.49, DISPLAY.50, DISPLAY.57, DISPLAY.58, DISPLAY.59; also elsewhere on the board
JOY_A: BOARD CONN.17; also elsewhere on the board
JOY_B: BOARD CONN.18; also elsewhere on the board
JOY_DOWN: BOARD CONN.12; also elsewhere on the board
JOY_LEFT: BOARD CONN.11; also elsewhere on the board
JOY_RIGHT: BOARD CONN.14; also elsewhere on the board
JOY_SELECT: BOARD CONN.15; also elsewhere on the board
JOY_START: BOARD CONN.16; also elsewhere on the board
JOY_UP: BOARD CONN.13; also elsewhere on the board
unnamed 48: DISPLAY.60; also elsewhere on the board
unnamed 55: DISPLAY.8; also elsewhere on the board
unnamed 56: DISPLAY.9; also elsewhere on the board
unnamed 57: DISPLAY.11; also elsewhere on the board
unnamed 58: DISPLAY.12; also elsewhere on the board
unnamed 59: DISPLAY.13; also elsewhere on the board
unnamed 60: DISPLAY.17; also elsewhere on the board
unnamed 61: DISPLAY.18; also elsewhere on the board
unnamed 62: DISPLAY.19; also elsewhere on the board
unnamed 63: DISPLAY.20; also elsewhere on the board
unnamed 64: DISPLAY.21; also elsewhere on the board
unnamed 65: DISPLAY.24; also elsewhere on the board
unnamed 66: DISPLAY.25; also elsewhere on the board
unnamed 67: DISPLAY.26; also elsewhere on the board
unnamed 68: DISPLAY.27; also elsewhere on the board
unnamed 69: DISPLAY.28; also elsewhere on the board
unnamed 70: DISPLAY.29; also elsewhere on the board
unnamed 71: DISPLAY.33; also elsewhere on the board
unnamed 72: DISPLAY.34; also elsewhere on the board
unnamed 73: DISPLAY.35; also elsewhere on the board
unnamed 74: DISPLAY.36; also elsewhere on the board
unnamed 75: DISPLAY.37; also elsewhere on the board
unnamed 76: DISPLAY.39; also elsewhere on the board
unnamed 77: DISPLAY.40; also elsewhere on the board
unnamed 78: DISPLAY.41; also elsewhere on the board
unnamed 79: DISPLAY.42; also elsewhere on the board
VOUT: BOARD CONN.2, BOARD CONN.3, BOARD CONN.4, BOARD CONN.5; also elsewhere on the board

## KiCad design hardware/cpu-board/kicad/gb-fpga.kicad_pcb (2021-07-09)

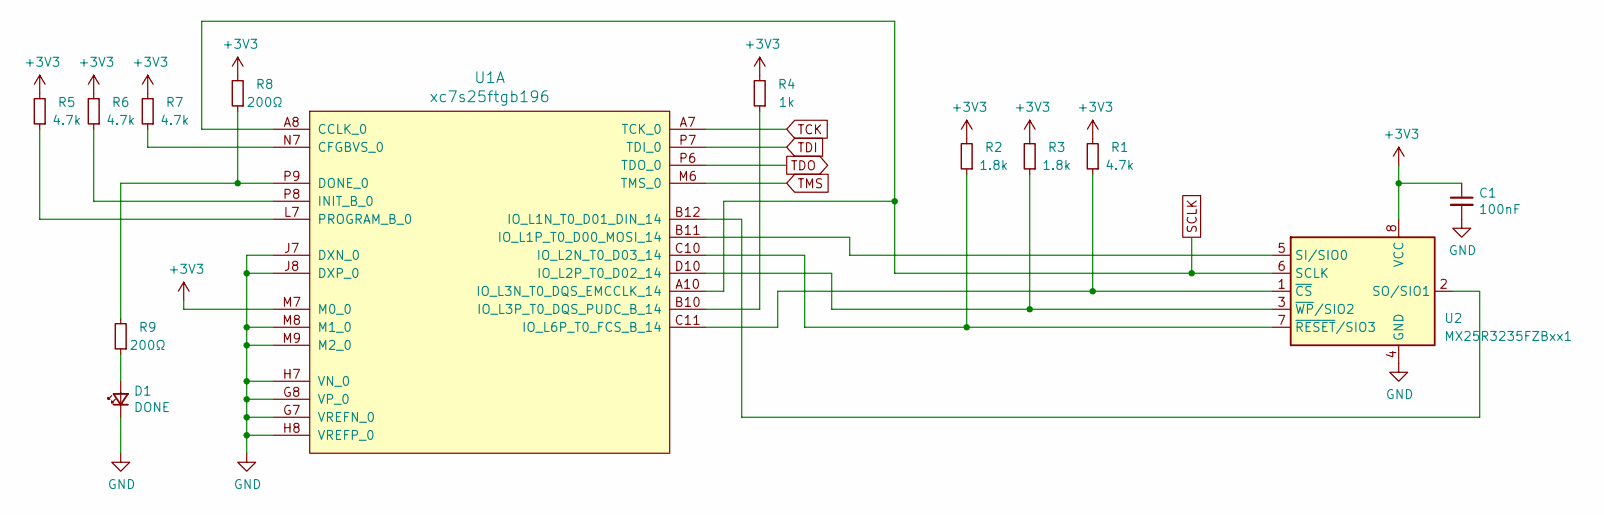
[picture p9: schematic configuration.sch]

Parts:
C1: 100nF; C_0402_1005Metric; Manufacturer Part Number CL05B104KO5NNNC
D1: DONE; LED_0402_1005Metric; Manufacturer Part Number NCD0402G1
R1, R5, R6, R7: 4.7k; R_0402_1005Metric; Manufacturer Part Number RC0402JR-074K7L
R2, R3: 1.8k; R_0402_1005Metric; Manufacturer Part Number RC0402JR-071K8L
R4: 1k; R_0402_1005Metric; Manufacturer Part Number RC0402JR-071KL
R8, R9: 200Ω; R_0402_1005Metric; Manufacturer Part Number AC0402JR-07200RL
U1: xc7s25ftgb196; Manufacturer Part Number XC7S25-1FTGB196C
U2: MX25R3235FZBxx1; USON-8_4.0x3.0mm_P0.8mm; Manufacturer Part Number MX25L3233FZBI-08Q

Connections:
+3V3: C1.1, R1.2, R2.2, R3.2, R4.2, R5.2, R6.2, R7.2, R8.2, U1.M7 (M0_0), U2.8 (VCC); also elsewhere on the board
GND: C1.2, D1.1 (K), U1.G7 (VREFN_0), U1.G8 (VP_0), U1.H7 (VN_0), U1.H8 (VREFP_0), U1.J7 (DXN_0), U1.J8 (DXP_0), U1.M8 (M1_0), U1.M9 (M2_0), U2.4 (GND), U2.9 (GND); also elsewhere on the board
unnamed: D1.2 (A), R9.1
unnamed: R1.1, U1.C11 (IO_L6P_T0_FCS_B_14), U2.1 (~CS)
unnamed: R2.1, U1.C10 (IO_L2N_T0_D03_14), U2.7 (~RESET~/SIO3)
unnamed: R3.1, U1.D10 (IO_L2P_T0_D02_14), U2.3 (~WP~/SIO2)
unnamed: R4.1, U1.B10 (IO_L3P_T0_DQS_PUDC_B_14)
unnamed: R5.1, U1.L7 (PROGRAM_B_0)
unnamed: R6.1, U1.P8 (INIT_B_0)
unnamed: R7.1, U1.N7 (CFGBVS_0)
unnamed: R8.1, R9.2, U1.P9 (DONE_0)
unnamed: U1.B11 (IO_L1P_T0_D00_MOSI_14), U2.5 (SI/SIO0)
unnamed: U1.B12 (IO_L1N_T0_D01_DIN_14), U2.2 (SO/SIO1)
SCLK: U1.A8 (CCLK_0), U1.A10 (IO_L3N_T0_DQS_EMCCLK_14), U2.6 (SCLK); also elsewhere on the board
TCK: U1.A7 (TCK_0); also elsewhere on the board
TDI: U1.P7 (TDI_0); also elsewhere on the board
TDO: U1.P6 (TDO_0); also elsewhere on the board
TMS: U1.M6 (TMS_0); also elsewhere on the board

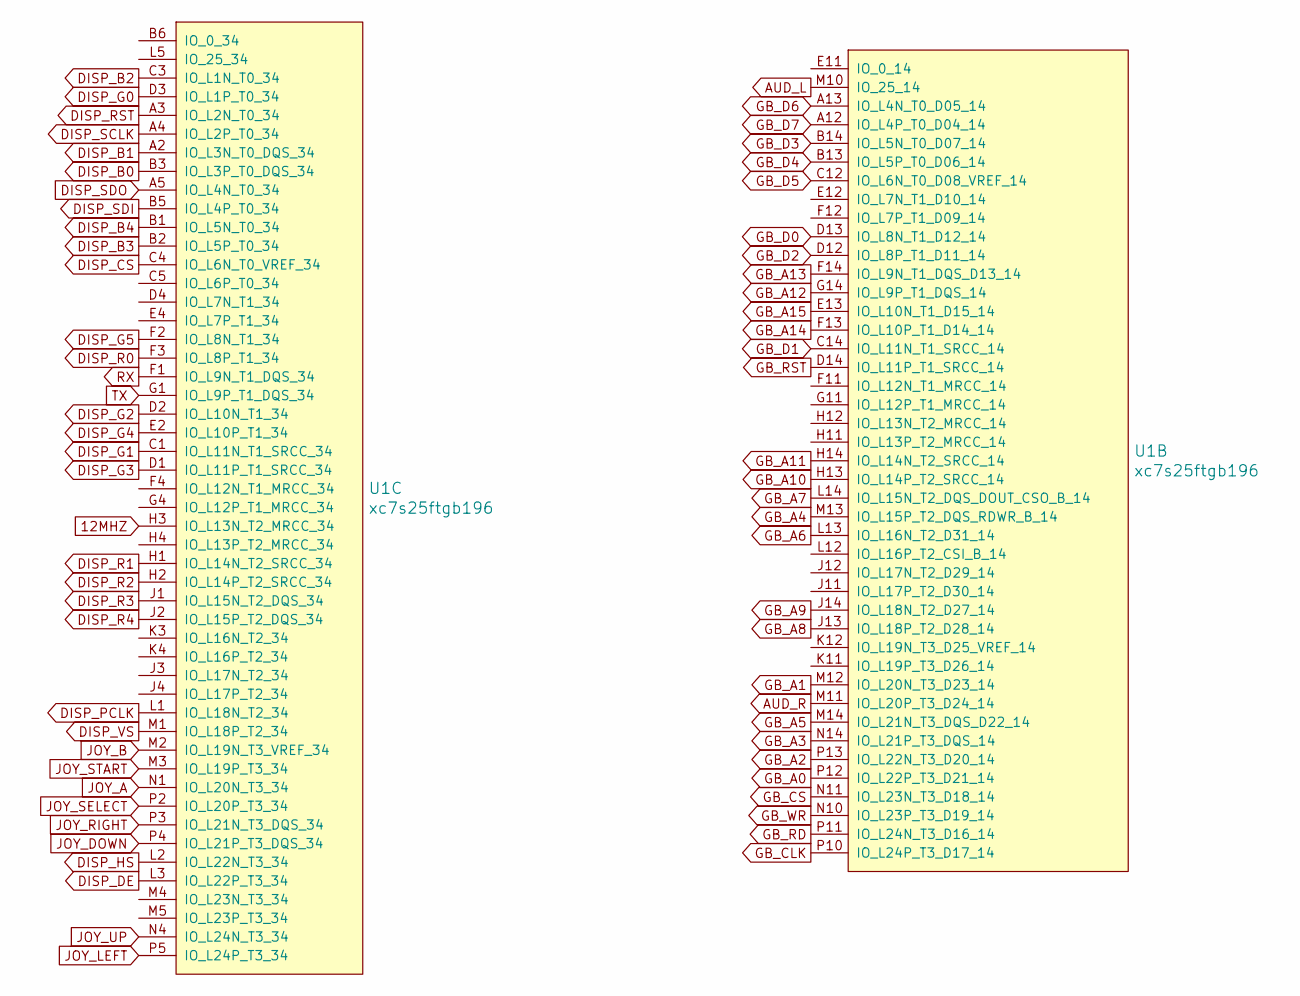
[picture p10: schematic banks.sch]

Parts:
U1: xc7s25ftgb196; Manufacturer Part Number XC7S25-1FTGB196C

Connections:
12MHZ: U1.H3 (IO_L13N_T2_MRCC_34); also elsewhere on the board
AUD_L: U1.M10 (IO_25_14); also elsewhere on the board
AUD_R: U1.M11 (IO_L20P_T3_D24_14); also elsewhere on the board
DISP_B0: U1.B3 (IO_L3P_T0_DQS_34); also elsewhere on the board
DISP_B1: U1.A2 (IO_L3N_T0_DQS_34); also elsewhere on the board
DISP_B2: U1.C3 (IO_L1N_T0_34); also elsewhere on the board
DISP_B3: U1.B2 (IO_L5P_T0_34); also elsewhere on the board
DISP_B4: U1.B1 (IO_L5N_T0_34); also elsewhere on the board
DISP_CS: U1.C4 (IO_L6N_T0_VREF_34); also elsewhere on the board
DISP_DE: U1.L3 (IO_L22P_T3_34); also elsewhere on the board
DISP_G0: U1.D3 (IO_L1P_T0_34); also elsewhere on the board
DISP_G1: U1.C1 (IO_L11N_T1_SRCC_34); also elsewhere on the board
DISP_G2: U1.D2 (IO_L10N_T1_34); also elsewhere on the board
DISP_G3: U1.D1 (IO_L11P_T1_SRCC_34); also elsewhere on the board
DISP_G4: U1.E2 (IO_L10P_T1_34); also elsewhere on the board
DISP_G5: U1.F2 (IO_L8N_T1_34); also elsewhere on the board
DISP_HS: U1.L2 (IO_L22N_T3_34); also elsewhere on the board
DISP_PCLK: U1.L1 (IO_L18N_T2_34); also elsewhere on the board
DISP_R0: U1.F3 (IO_L8P_T1_34); also elsewhere on the board
DISP_R1: U1.H1 (IO_L14N_T2_SRCC_34); also elsewhere on the board
DISP_R2: U1.H2 (IO_L14P_T2_SRCC_34); also elsewhere on the board
DISP_R3: U1.J1 (IO_L15N_T2_DQS_34); also elsewhere on the board
DISP_R4: U1.J2 (IO_L15P_T2_DQS_34); also elsewhere on the board
DISP_RST: U1.A3 (IO_L2N_T0_34); also elsewhere on the board
DISP_SCLK: U1.A4 (IO_L2P_T0_34); also elsewhere on the board
DISP_SDI: U1.B5 (IO_L4P_T0_34); also elsewhere on the board
DISP_SDO: U1.A5 (IO_L4N_T0_34); also elsewhere on the board
DISP_VS: U1.M1 (IO_L18P_T2_34); also elsewhere on the board
GB_A0: U1.P12 (IO_L22P_T3_D21_14); also elsewhere on the board
GB_A1: U1.M12 (IO_L20N_T3_D23_14); also elsewhere on the board
GB_A2: U1.P13 (IO_L22N_T3_D20_14); also elsewhere on the board
GB_A3: U1.N14 (IO_L21P_T3_DQS_14); also elsewhere on the board
GB_A4: U1.M13 (IO_L15P_T2_DQS_RDWR_B_14); also elsewhere on the board
GB_A5: U1.M14 (IO_L21N_T3_DQS_D22_14); also elsewhere on the board
GB_A6: U1.L13 (IO_L16N_T2_D31_14); also elsewhere on the board
GB_A7: U1.L14 (IO_L15N_T2_DQS_DOUT_CSO_B_14); also elsewhere on the board
GB_A8: U1.J13 (IO_L18P_T2_D28_14); also elsewhere on the board
GB_A9: U1.J14 (IO_L18N_T2_D27_14); also elsewhere on the board
GB_A10: U1.H13 (IO_L14P_T2_SRCC_14); also elsewhere on the board
GB_A11: U1.H14 (IO_L14N_T2_SRCC_14); also elsewhere on the board
GB_A12: U1.G14 (IO_L9P_T1_DQS_14); also elsewhere on the board
GB_A13: U1.F14 (IO_L9N_T1_DQS_D13_14); also elsewhere on the board
GB_A14: U1.F13 (IO_L10P_T1_D14_14); also elsewhere on the board
GB_A15: U1.E13 (IO_L10N_T1_D15_14); also elsewhere on the board
GB_CLK: U1.P10 (IO_L24P_T3_D17_14); also elsewhere on the board
GB_CS: U1.N11 (IO_L23N_T3_D18_14); also elsewhere on the board
GB_D0: U1.D13 (IO_L8N_T1_D12_14); also elsewhere on the board
GB_D1: U1.C14 (IO_L11N_T1_SRCC_14); also elsewhere on the board
GB_D2: U1.D12 (IO_L8P_T1_D11_14); also elsewhere on the board
GB_D3: U1.B14 (IO_L5N_T0_D07_14); also elsewhere on the board
GB_D4: U1.B13 (IO_L5P_T0_D06_14); also elsewhere on the board
GB_D5: U1.C12 (IO_L6N_T0_D08_VREF_14); also elsewhere on the board
GB_D6: U1.A13 (IO_L4N_T0_D05_14); also elsewhere on the board
GB_D7: U1.A12 (IO_L4P_T0_D04_14); also elsewhere on the board
GB_RD: U1.P11 (IO_L24N_T3_D16_14); also elsewhere on the board
GB_RST: U1.D14 (IO_L11P_T1_SRCC_14); also elsewhere on the board
GB_WR: U1.N10 (IO_L23P_T3_D19_14); also elsewhere on the board
JOY_A: U1.N1 (IO_L20N_T3_34); also elsewhere on the board
JOY_B: U1.M2 (IO_L19N_T3_VREF_34); also elsewhere on the board
JOY_DOWN: U1.P4 (IO_L21P_T3_DQS_34); also elsewhere on the board
JOY_LEFT: U1.P5 (IO_L24P_T3_34); also elsewhere on the board
JOY_RIGHT: U1.P3 (IO_L21N_T3_DQS_34); also elsewhere on the board
JOY_SELECT: U1.P2 (IO_L20P_T3_34); also elsewhere on the board
JOY_START: U1.M3 (IO_L19P_T3_34); also elsewhere on the board
JOY_UP: U1.N4 (IO_L24N_T3_34); also elsewhere on the board
RX: U1.F1 (IO_L9N_T1_DQS_34); also elsewhere on the board
TX: U1.G1 (IO_L9P_T1_DQS_34); also elsewhere on the board

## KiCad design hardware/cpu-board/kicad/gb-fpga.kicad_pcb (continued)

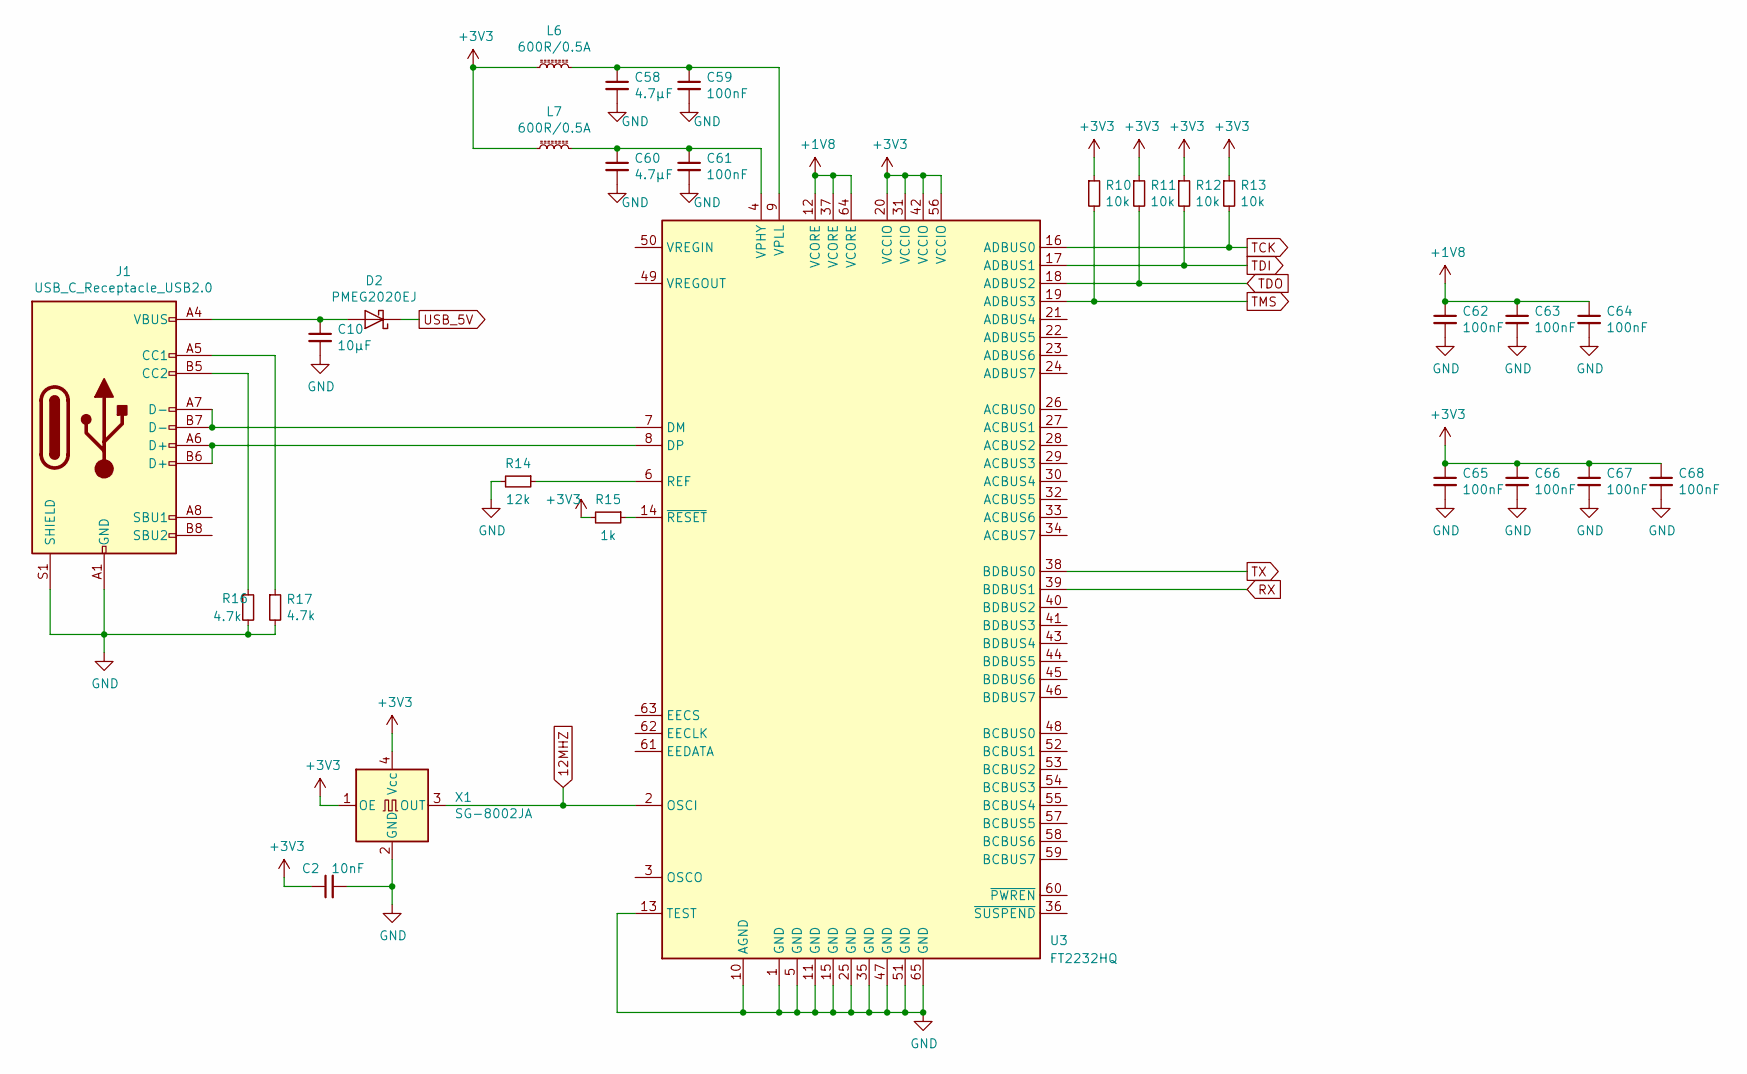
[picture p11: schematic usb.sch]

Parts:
C2: 10nF; C_0402_1005Metric; Manufacturer Part Number CL05B103KB5NNNC
C10: 10µF; C_0402_1005Metric; Manufacturer Part Number CL05A106MP5NUNC
C58, C60: 4.7µF; C_0402_1005Metric; Manufacturer Part Number CL05A475KP5NRNC
C59, C61, C62, C63, C64, C65, C66, C67, C68: 100nF; C_0402_1005Metric; Manufacturer Part Number CL05B104KO5NNNC
D2: PMEG2020EJ; D_SOD-323F; Manufacturer Part Number PMEG2020EJF
J1: USB_C_Receptacle_USB2.0; USB_C_Receptacle_XKB_U262-16XN-4BVC11; Manufacturer Part Number U262-161N-4BVC11
L6, L7: 600R/0.5A; L_0402_1005Metric; Manufacturer Part Number BLM15AX601SN1D
R10, R11, R12, R13: 10k; R_0402_1005Metric; Manufacturer Part Number RC0402JR-0710KL
R14: 12k; R_0402_1005Metric; Manufacturer Part Number RC0402FR-0712KL
R15: 1k; R_0402_1005Metric; Manufacturer Part Number RC0402JR-071KL
R16, R17: 4.7k; R_0402_1005Metric; Manufacturer Part Number RC0402JR-074K7L
U3: FT2232HQ; QFN-64-1EP_9x9mm_P0.5mm_EP4.35x4.35mm; Manufacturer Part Number FT2232HQ-REEL
X1: SG-8002JA; Oscillator_SMD_Abracon_ASE-4Pin_3.2x2.5mm; Manufacturer Part Number CB3LV-3C-12M000000

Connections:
12MHZ: U3.2 (OSCI), X1.3 (OUT); also elsewhere on the board
+1V8: C62.1, C63.1, C64.1, U3.12 (VCORE), U3.37 (VCORE), U3.64 (VCORE); also elsewhere on the board
+3V3: C2.1, C65.1, C66.1, C67.1, C68.1, L6.1, L7.1, R10.1, R11.1, R12.1, R13.1, R15.2, U3.20 (VCCIO), U3.31 (VCCIO), U3.42 (VCCIO), U3.56 (VCCIO), X1.1 (OE), X1.4 (Vcc); also elsewhere on the board
GND: C2.2, C10.2, C58.2, C59.2, C60.2, C61.2, C62.2, C63.2, C64.2, C65.2, C66.2, C67.2, C68.2, J1.A1 (GND), J1.A12 (GND), J1.B1 (GND), J1.B12 (GND), J1.S1 (SHIELD), R14.2, R16.2, R17.2, U3.1 (GND), U3.5 (GND), U3.10 (AGND), U3.11 (GND), U3.13 (TEST), U3.15 (GND), U3.25 (GND), U3.35 (GND), U3.47 (GND), U3.51 (GND), U3.65 (GND), X1.2 (GND); also elsewhere on the board
unnamed: C10.1, D2.2 (A), J1.A4 (VBUS), J1.A9 (VBUS), J1.B4 (VBUS), J1.B9 (VBUS)
unnamed: C58.1, C59.1, L6.2, U3.9 (VPLL)
unnamed: C60.1, C61.1, L7.2, U3.4 (VPHY)
unnamed: J1.A5 (CC1), R17.1
unnamed: J1.A6 (D+), J1.B6 (D+), U3.8 (DP)
unnamed: J1.A7 (D-), J1.B7 (D-), U3.7 (DM)
unnamed: J1.B5 (CC2), R16.1
unnamed: R14.1, U3.6 (REF)
unnamed: R15.1, U3.14 (~RESET)
RX: U3.39 (BDBUS1); also elsewhere on the board
TCK: R13.2, U3.16 (ADBUS0); also elsewhere on the board
TDI: R12.2, U3.17 (ADBUS1); also elsewhere on the board
TDO: R11.2, U3.18 (ADBUS2); also elsewhere on the board
TMS: R10.2, U3.19 (ADBUS3); also elsewhere on the board
TX: U3.38 (BDBUS0); also elsewhere on the board
USB_5V: D2.1 (K); also elsewhere on the board

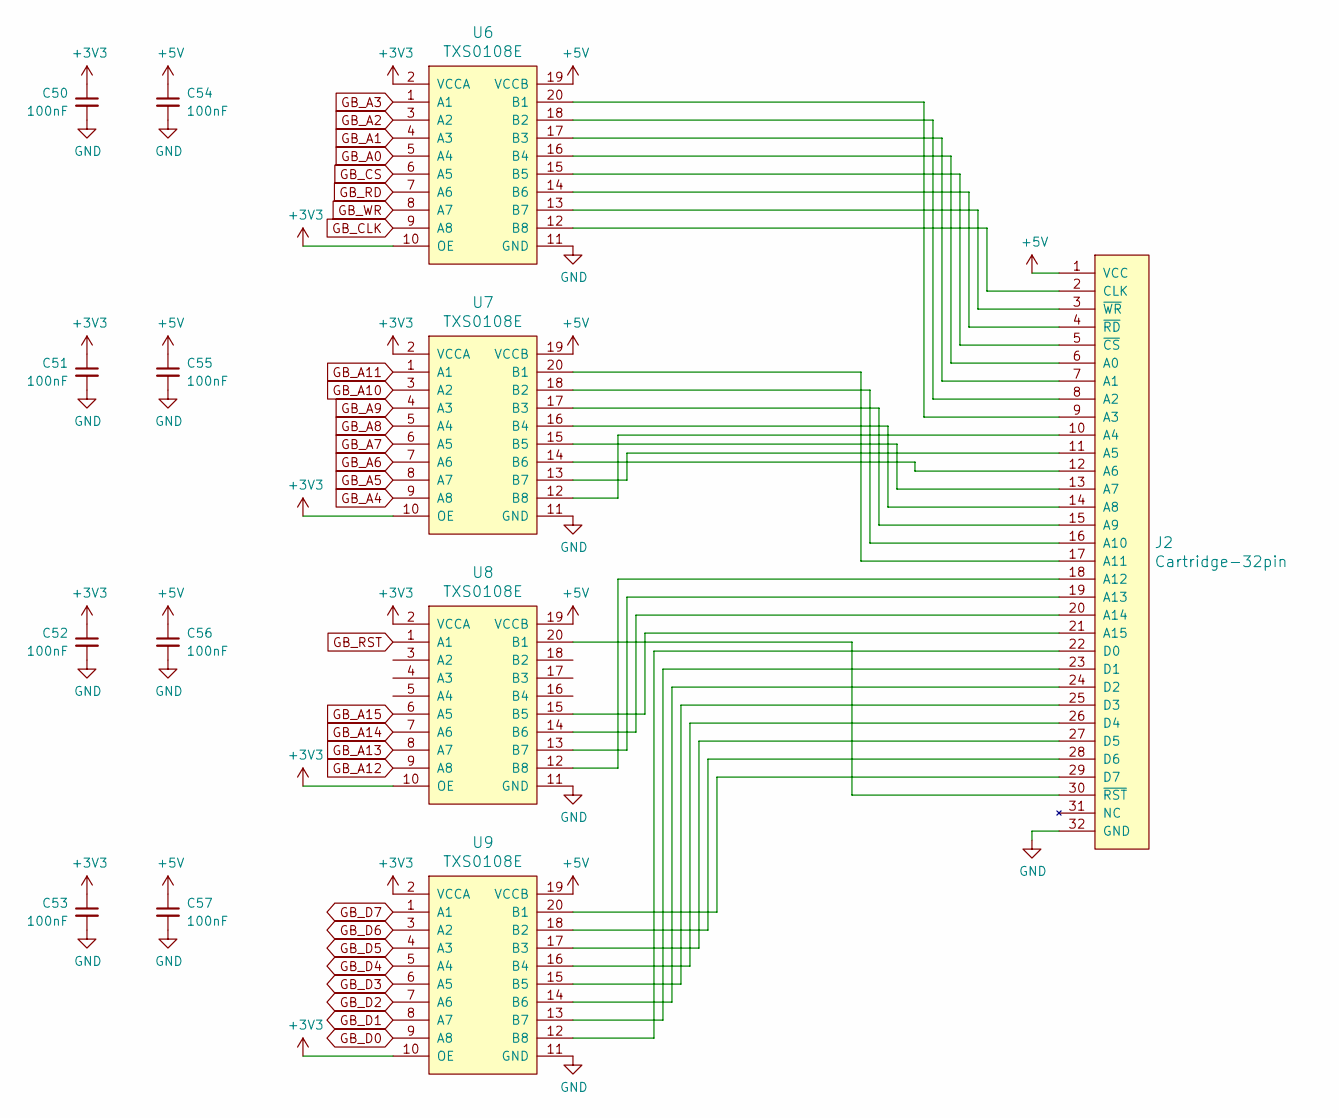
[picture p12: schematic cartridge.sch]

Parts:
C50, C51, C52, C53, C54, C55, C56, C57: 100nF; C_0402_1005Metric; Manufacturer Part Number CL05B104KO5NNNC
J2: Cartridge-32pin; Cartridge-DMG
U6, U7, U8, U9: TXS0108E; TSSOP-20_4.4x6.5mm_P0.65mm; Manufacturer Part Number TXS0108EPWR

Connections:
+3V3: C50.1, C51.1, C52.1, C53.1, U6.2 (VCCA), U6.10 (OE), U7.2 (VCCA), U7.10 (OE), U8.2 (VCCA), U8.10 (OE), U9.2 (VCCA), U9.10 (OE); also elsewhere on the board
+5V: C54.1, C55.1, C56.1, C57.1, J2.1 (VCC), U6.19 (VCCB), U7.19 (VCCB), U8.19 (VCCB), U9.19 (VCCB); also elsewhere on the board
GB_A0: U6.5 (A4); also elsewhere on the board
GB_A1: U6.4 (A3); also elsewhere on the board
GB_A2: U6.3 (A2); also elsewhere on the board
GB_A3: U6.1 (A1); also elsewhere on the board
GB_A4: U7.9 (A8); also elsewhere on the board
GB_A5: U7.8 (A7); also elsewhere on the board
GB_A6: U7.7 (A6); also elsewhere on the board
GB_A7: U7.6 (A5); also elsewhere on the board
GB_A8: U7.5 (A4); also elsewhere on the board
GB_A9: U7.4 (A3); also elsewhere on the board
GB_A10: U7.3 (A2); also elsewhere on the board
GB_A11: U7.1 (A1); also elsewhere on the board
GB_A12: U8.9 (A8); also elsewhere on the board
GB_A13: U8.8 (A7); also elsewhere on the board
GB_A14: U8.7 (A6); also elsewhere on the board
GB_A15: U8.6 (A5); also elsewhere on the board
GB_CLK: U6.9 (A8); also elsewhere on the board
GB_CS: U6.6 (A5); also elsewhere on the board
GB_D0: U9.9 (A8); also elsewhere on the board
GB_D1: U9.8 (A7); also elsewhere on the board
GB_D2: U9.7 (A6); also elsewhere on the board
GB_D3: U9.6 (A5); also elsewhere on the board
GB_D4: U9.5 (A4); also elsewhere on the board
GB_D5: U9.4 (A3); also elsewhere on the board
GB_D6: U9.3 (A2); also elsewhere on the board
GB_D7: U9.1 (A1); also elsewhere on the board
GB_RD: U6.7 (A6); also elsewhere on the board
GB_RST: U8.1 (A1); also elsewhere on the board
GB_WR: U6.8 (A7); also elsewhere on the board
GND: C50.2, C51.2, C52.2, C53.2, C54.2, C55.2, C56.2, C57.2, J2.32 (GND), U6.11 (GND), U7.11 (GND), U8.11 (GND), U9.11 (GND); also elsewhere on the board
unnamed: J2.2 (CLK), U6.12 (B8)
unnamed: J2.3 (~WR~), U6.13 (B7)
unnamed: J2.4 (~RD~), U6.14 (B6)
unnamed: J2.5 (~CS~), U6.15 (B5)
unnamed: J2.6 (A0), U6.16 (B4)
unnamed: J2.7 (A1), U6.17 (B3)
unnamed: J2.8 (A2), U6.18 (B2)
unnamed: J2.9 (A3), U6.20 (B1)
unnamed: J2.10 (A4), U7.12 (B8)
unnamed: J2.11 (A5), U7.13 (B7)
unnamed: J2.12 (A6), U7.14 (B6)
unnamed: J2.13 (A7), U7.15 (B5)
unnamed: J2.14 (A8), U7.16 (B4)
unnamed: J2.15 (A9), U7.17 (B3)
unnamed: J2.16 (A10), U7.18 (B2)
unnamed: J2.17 (A11), U7.20 (B1)
unnamed: J2.18 (A12), U8.12 (B8)
unnamed: J2.19 (A13), U8.13 (B7)
unnamed: J2.20 (A14), U8.14 (B6)
unnamed: J2.21 (A15), U8.15 (B5)
unnamed: J2.22 (D0), U9.12 (B8)
unnamed: J2.23 (D1), U9.13 (B7)
unnamed: J2.24 (D2), U9.14 (B6)
unnamed: J2.25 (D3), U9.15 (B5)
unnamed: J2.26 (D4), U9.16 (B4)
unnamed: J2.27 (D5), U9.17 (B3)
unnamed: J2.28 (D6), U9.18 (B2)
unnamed: J2.29 (D7), U9.20 (B1)
unnamed: J2.30 (~RST~), U8.20 (B1)


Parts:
C14, C18: 47µF; C_0603_1608Metric; Manufacturer Part Number CL10A476MQ8QRNC
C15, C19, C22, C23, C28, C29, C35, C36, C42, C43: 4.7µF; C_0201_0603Metric; Manufacturer Part Number GRM035R60J475ME15D
C16, C17, C20, C24, C25, C26, C30, C31, C32, C33, C37, C38, C39, C40, C44, C45, C46, C47: 470nF; C_0201_0603Metric; Manufacturer Part Number GRM033R60J474KE90D
C21, C27, C34, C41: 100µF; C_1206_3216Metric; Manufacturer Part Number GRM31CR61A107ME05L
U1: xc7s25ftgb196; Xilinx_FTGB196; Manufacturer Part Number XC7S25-1FTGB196C

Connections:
+1V0: C18.1, C19.1, C20.1, C21.1, C22.1, C23.1, C24.1, C25.1, C26.1, U1.D6 (VCCINT[10]), U1.D8 (VCCINT[10]), U1.E5 (VCCBRAM[3]), U1.E7 (VCCINT[10]), U1.E9 (VCCINT[10]), U1.F6 (VCCINT[10]), U1.G5 (VCCBRAM[3]), U1.G9 (VCCINT[10]), U1.H6 (VCCINT[10]), U1.J5 (VCCBRAM[3]), U1.J9 (VCCINT[10]), U1.K6 (VCCINT[10]), U1.K8 (VCCINT[10]); also elsewhere on the board
+1V8: C14.1, C15.1, C16.1, C17.1, U1.B8 (VCCBATT_0), U1.F8 (VCCADC_0), U1.F10 (VCCAUX[4]), U1.H10 (VCCAUX[4]), U1.K10 (VCCAUX[4]), U1.L9 (VCCAUX[4]); also elsewhere on the board
+3V3: C27.1, C28.1, C29.1, C30.1, C31.1, C32.1, C33.1, C34.1, C35.1, C36.1, C37.1, C38.1, C39.1, C40.1, C41.1, C42.1, C43.1, C44.1, C45.1, C46.1, C47.1, U1.G2 (VCCO_34[3]), U1.G13 (VCCO_14[3]), U1.K2 (VCCO_34[3]), U1.K13 (VCCO_14[3]), U1.N2 (VCCO_34[3]), U1.N6 (VCCO_0[2]), U1.N8 (VCCO_0[2]), U1.N13 (VCCO_14[3]); also elsewhere on the board
GND: C14.2, C15.2, C16.2, C17.2, C18.2, C19.2, C20.2, C21.2, C22.2, C23.2, C24.2, C25.2, C26.2, C27.2, C28.2, C29.2, C30.2, C31.2, C32.2, C33.2, C34.2, C35.2, C36.2, C37.2, C38.2, C39.2, C40.2, C41.2, C42.2, C43.2, C44.2, C45.2, C46.2, C47.2, U1.A1 (GND[50]), U1.A6 (GND[50]), U1.A9 (GND[50]), U1.A11 (GND[50]), U1.A14 (GND[50]), U1.B4 (GND[50]), U1.B7 (GND[50]), U1.B9 (GND[50]), U1.C2 (GND[50]), U1.C6 (GND[50]), U1.C7 (GND[50]), U1.C8 (GND[50]), U1.C9 (GND[50]), U1.C13 (GND[50]), U1.D5 (GND[50]), U1.D7 (GND[50]), U1.D9 (GND[50]), U1.D11 (GND[50]), U1.E1 (GND[50]), U1.E3 (GND[50]), U1.E6 (GND[50]), U1.E8 (GND[50]), U1.E10 (GND[50]), U1.E14 (GND[50]), U1.F5 (GND[50]), U1.F7 (GNDADC_0), U1.F9 (GND[50]), U1.G3 (GND[50]), U1.G6 (GND[50]), U1.G10 (GND[50]), U1.G12 (GND[50]), U1.H5 (GND[50]), U1.H9 (GND[50]), U1.J6 (GND[50]), U1.J10 (GND[50]), U1.K1 (GND[50]), U1.K5 (GND[50]), U1.K7 (GND[50]), U1.K9 (GND[50]), U1.K14 (GND[50]), U1.L4 (GND[50]), U1.L6 (GND[50]), U1.L8 (GND[50]), U1.L10 (GND[50]), U1.L11 (GND[50]), U1.N3 (GND[50]), U1.N5 (GND[50]), U1.N9 (GND[50]), U1.N12 (GND[50]), U1.P1 (GND[50]), U1.P14 (GND[50]); also elsewhere on the board


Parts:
C3: 470nF; C_0402_1005Metric; Manufacturer Part Number CL05A474KP5NNNC
C4, C6, C8: 20pF; C_0402_1005Metric; Manufacturer Part Number CL05C220JB5NNNC
C5, C11: 22µF; C_0402_1005Metric; Manufacturer Part Number GRM155R60J226ME11D
C7, C9: 10µF; C_0402_1005Metric; Manufacturer Part Number CL05A106MP5NUNC
C12: 1µF; C_0402_1005Metric; Manufacturer Part Number CL05A105KO5NNNC
C13: 4.7µF; C_0402_1005Metric; Manufacturer Part Number CL05A475KP5NRNC
D3: CHRG; LED_0402_1005Metric; Manufacturer Part Number NCD0402B1
J3: BAT+; PinHeader_1x01_P2.54mm_Vertical
J4: BAT-; PinHeader_1x01_P2.54mm_Vertical
L1: 1.5µH; L_0402_1005Metric; Manufacturer Part Number SDFL1005Q1R5KTF
L2, L4: 3.3µH; L_0402_1005Metric; Manufacturer Part Number SDFL1005Q3R3KTF
L3: 2.2µH; L_0402_1005Metric; Manufacturer Part Number SDFL1005Q2R2KTF
L5: 10µH; L_0603_1608Metric; Manufacturer Part Number SDFL1608S100KTF
Q1: MBT3904DW1; SOT-363_SC-70-6; Manufacturer Part Number MBT3904DW1T1H
R18, R27: 3k; R_0402_1005Metric; Manufacturer Part Number RC0402FR-073KL
R19: 2k; R_0402_1005Metric; Manufacturer Part Number RC0402FR-072KL
R20, R29, R30: 30k; R_0402_1005Metric; Manufacturer Part Number AF0402FR-0730KL
R21, R23: 120k; R_0402_1005Metric; Manufacturer Part Number RC0402FR-07120KL
R22: 150k; R_0402_1005Metric; Manufacturer Part Number RC0402FR-07150KL
R24, R34: 180k; R_0402_1005Metric; Manufacturer Part Number RC0402FR-07180KL
R25: 57.6k; R_0402_1005Metric; Manufacturer Part Number RC0402FR-0757K6L
R26, R28: 10k; R_0402_1005Metric; Manufacturer Part Number RC0402JR-0710KL
R31: 1k; R_0402_1005Metric; Manufacturer Part Number RC0402JR-071KL
R32: 200Ω; R_0402_1005Metric; Manufacturer Part Number AC0402JR-07200RL
R33: 953k; R_0402_1005Metric; Manufacturer Part Number RC0402FR-07953KL
SW1: Switch; EG2215; Manufacturer Part Number EG2215
U4: LTC3555; QFN-28-1EP_4x5mm_P0.5mm_EP2.65x3.65mm; Manufacturer Part Number LTC3555IUFD-1#PBF
U5: TLV61046ADB; SOT-23-6; Manufacturer Part Number TLV61046ADBVR

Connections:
+1V0: C4.1, C5.1, L1.2, R20.1, R31.1; also elsewhere on the board
+1V8: C6.1, C7.1, L2.2, R22.1, R27.1; also elsewhere on the board
+3V3: C8.1, C9.1, L3.2, R24.1; also elsewhere on the board
+5V: C13.1, R33.1, U5.5 (VOUT); also elsewhere on the board
GND: C3.2, C5.2, C7.2, C9.2, C11.2, C12.2, C13.2, J4.1, Q1.1 (E1), Q1.4 (E2), R18.2, R19.2, R21.1, R23.1, R25.1, R26.2, R28.2, R34.2, SW1.4 (GND), U4.3 (NTC), U4.8 (DVCC), U4.29 (GND), U5.2 (GND); also elsewhere on the board
unnamed: C3.1, R18.1, U4.2 (CLPROG)
unnamed: C4.2, R20.2, R21.2, U4.19 (FB1)
unnamed: C6.2, R22.2, R23.2, U4.4 (FB2)
unnamed: C8.2, R24.2, R25.2, U4.14 (FB3)
unnamed: C11.1, L4.2, R32.1, SW1.2, U4.1 (LDO3V3), U4.24 (VOUT)
unnamed: D3.1 (K), U4.21 (~CHRG)
unnamed: D3.2 (A), R32.2
unnamed: J3.1, U4.23 (BAT)
unnamed: L1.1, U4.17 (SW1)
unnamed: L2.1, U4.6 (SW2)
unnamed: L3.1, U4.12 (SW3)
unnamed: L4.1, U4.26 (SW)
unnamed: L5.2, U5.1 (SW)
unnamed: Q1.2 (B1), Q1.3 (C2), R30.2
unnamed: Q1.5 (B2), R31.2
unnamed: Q1.6 (C1), R29.2, U4.7 (EN2)
unnamed: R19.1, U4.20 (PROG)
unnamed: R27.2, R28.1, U4.13 (EN3)
unnamed: R33.2, R34.1, U5.3 (FB)
USB_5V: U4.9 (SCL), U4.10 (SDA), U4.25 (VBUS), U4.27 (ILIM0), U4.28 (ILIM1); also elsewhere on the board
VOUT: C12.1, L5.1, R26.1, R29.1, R30.1, SW1.3, U4.5 (VIN2), U4.11 (VIN3), U4.16 (EN1), U4.18 (VIN1), U5.4 (EN), U5.6 (VI); also elsewhere on the board


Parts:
C48, C49: 4.7nF; C_0402_1005Metric; Manufacturer Part Number CL05B472KA5NNNC
J5: Conn_02x25_Counter_Clockwise; Hirose_FH12-50S-0.5SH_1x50-1MP_P0.50mm_Horizontal; Manufacturer Part Number FH12-50S-0.5SH(55)
R35, R36: 1k; R_0402_1005Metric; Manufacturer Part Number RC0402JR-071KL
RV1: 25k; Dual_Pot

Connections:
+3V3: J5.50; also elsewhere on the board
+5V: J5.1; also elsewhere on the board
AUD_L: R36.1; also elsewhere on the board
AUD_R: R35.1; also elsewhere on the board
DISP_B0: J5.10; also elsewhere on the board
DISP_B1: J5.11; also elsewhere on the board
DISP_B2: J5.12; also elsewhere on the board
DISP_B3: J5.13; also elsewhere on the board
DISP_B4: J5.14; also elsewhere on the board
DISP_CS: J5.7; also elsewhere on the board
DISP_DE: J5.27; also elsewhere on the board
DISP_G0: J5.15; also elsewhere on the board
DISP_G1: J5.16; also elsewhere on the board
DISP_G2: J5.17; also elsewhere on the board
DISP_G3: J5.18; also elsewhere on the board
DISP_G4: J5.19; also elsewhere on the board
DISP_G5: J5.20; also elsewhere on the board
DISP_HS: J5.29; also elsewhere on the board
DISP_PCLK: J5.28; also elsewhere on the board
DISP_R0: J5.21; also elsewhere on the board
DISP_R1: J5.22; also elsewhere on the board
DISP_R2: J5.23; also elsewhere on the board
DISP_R3: J5.24; also elsewhere on the board
DISP_R4: J5.25; also elsewhere on the board
DISP_RST: J5.8; also elsewhere on the board
DISP_SCLK: J5.6; also elsewhere on the board
DISP_SDI: J5.5; also elsewhere on the board
DISP_SDO: J5.4; also elsewhere on the board
DISP_VS: J5.30; also elsewhere on the board
GND: C48.2, C49.2, J5.2, J5.3, J5.9, J5.26, J5.31, J5.32, J5.41, J5.44, J5.45, RV1.5; also elsewhere on the board
JOY_A: J5.34; also elsewhere on the board
JOY_B: J5.33; also elsewhere on the board
JOY_DOWN: J5.39; also elsewhere on the board
JOY_LEFT: J5.40; also elsewhere on the board
JOY_RIGHT: J5.37; also elsewhere on the board
JOY_SELECT: J5.36; also elsewhere on the board
JOY_START: J5.35; also elsewhere on the board
JOY_UP: J5.38; also elsewhere on the board
unnamed: C48.1, R35.2, RV1.2
unnamed: C49.1, R36.2, RV1.1
unnamed: J5.42, RV1.4
unnamed: J5.43, RV1.3
VOUT: J5.46, J5.47, J5.48, J5.49; also elsewhere on the board


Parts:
TP1: 1V0; TestPoint_Pad_1.0x1.0mm
TP2: 1V8; TestPoint_THTPad_1.0x1.0mm_Drill0.5mm
TP3: 3V3; TestPoint_THTPad_1.0x1.0mm_Drill0.5mm
TP4: 5V; TestPoint_THTPad_1.0x1.0mm_Drill0.5mm
TP5: USB5V; TestPoint_Pad_1.0x1.0mm
TP6: VOUT; TestPoint_THTPad_1.0x1.0mm_Drill0.5mm
TP7, TP8: GND; TestPoint_THTPad_1.5x1.5mm_Drill0.7mm
TP9: AUD_L; TestPoint_Pad_D1.0mm
TP10: AUD_R; TestPoint_Pad_D1.0mm
TP11: 12MHZ; TestPoint_Pad_D1.0mm
TP12: TCK; TestPoint_Pad_D1.0mm
TP13: SCLK; TestPoint_Pad_D1.0mm

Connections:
12MHZ: TP11.1; also elsewhere on the board
+1V0: TP1.1; also elsewhere on the board
+1V8: TP2.1; also elsewhere on the board
+3V3: TP3.1; also elsewhere on the board
+5V: TP4.1; also elsewhere on the board
AUD_L: TP9.1; also elsewhere on the board
AUD_R: TP10.1; also elsewhere on the board
GND: TP7.1, TP8.1; also elsewhere on the board
SCLK: TP13.1; also elsewhere on the board
TCK: TP12.1; also elsewhere on the board
USB_5V: TP5.1; also elsewhere on the board
VOUT: TP6.1; also elsewhere on the board



Board: 4 copper layers, 80.1 x 78.6 mm, 145 parts (35 on the bottom side), 151 nets.

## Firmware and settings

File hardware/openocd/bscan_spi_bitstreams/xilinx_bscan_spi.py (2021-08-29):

#!/usr/bin/python3
#
#  Copyright (C) 2015-2019 Robert Jordens <rj@quartiq.de>
#
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

import unittest

import migen as mg
import migen.build.generic_platform as mb
from migen.genlib import io
from migen.build import xilinx


"""
This migen script produces proxy bitstreams to allow programming SPI flashes
behind FPGAs.

Bitstream binaries built with this script are available at:
https://github.com/quartiq/bscan_spi_bitstreams

A JTAG2SPI transfer consists of:

1. an arbitrary number of 0 bits (from BYPASS registers in front of the
   JTAG2SPI DR)
2. a marker bit (1) indicating the start of the JTAG2SPI transaction
3. 32 bits (big endian) describing the length of the SPI transaction
4. a number of SPI clock cycles (corresponding to 3.) with CS_N asserted
5. an arbitrary number of cycles (to shift MISO/TDO data through subsequent
   BYPASS registers)

Notes:

* The JTAG2SPI DR is 1 bit long (due to different sampling edges of
  {MISO,MOSI}/{TDO,TDI}).
* MOSI is TDI with half a cycle delay.
* TDO is MISO with half a cycle delay.
* CAPTURE-DR needs to be performed before SHIFT-DR on the BYPASSed TAPs in
  JTAG chain to clear the BYPASS registers to 0.

https://github.com/m-labs/migen
"""


class JTAG2SPI(mg.Module):
    def __init__(self, spi=None, bits=32):
        self.jtag = mg.Record([
            ("sel", 1),
            ("shift", 1),
            ("capture", 1),
            ("tck", 1),
            ("tdi", 1),
            ("tdo", 1),
        ])
        self.cs_n = mg.TSTriple()
        self.clk = mg.TSTriple()
        self.mosi = mg.TSTriple()
        self.miso = mg.TSTriple()

        # # #

        self.cs_n.o.reset = mg.Constant(1)
        self.mosi.o.reset_less = True
        bits = mg.Signal(bits, reset_less=True)
        head = mg.Signal(max=len(bits), reset=len(bits) - 1)
        self.clock_domains.cd_sys = mg.ClockDomain()
        self.submodules.fsm = mg.FSM("IDLE")
        if spi is not None:
            self.specials += [
                self.cs_n.get_tristate(spi.cs_n),
                self.mosi.get_tristate(spi.mosi),
                self.miso.get_tristate(spi.miso),
            ]
            if hasattr(spi, "clk"):  # 7 Series drive it fixed
                self.specials += self.clk.get_tristate(spi.clk)
                # self.specials += io.DDROutput(1, 0, spi.clk, self.clk.o)
        self.comb += [
            self.cd_sys.rst.eq(self.jtag.sel & self.jtag.capture),
            self.cd_sys.clk.eq(self.jtag.tck),
            self.cs_n.oe.eq(self.jtag.sel),
            self.clk.oe.eq(self.jtag.sel),
            self.mosi.oe.eq(self.jtag.sel),
            self.miso.oe.eq(0),
            # Do not suppress CLK toggles outside CS_N asserted.
            # Xilinx USRCCLK0 requires three dummy cycles to do anything
            # https://www.xilinx.com/support/answers/52626.html
            # This is fine since CS_N changes only on falling CLK.
            self.clk.o.eq(~self.jtag.tck),
            self.jtag.tdo.eq(self.miso.i),
        ]
        # Latency calculation (in half cycles):
        # 0 (falling TCK, rising CLK):
        #   JTAG adapter: set TDI
        # 1 (rising TCK, falling CLK):
        #   JTAG2SPI: sample TDI -> set MOSI
        #   SPI: set MISO
        # 2 (falling TCK, rising CLK):
        #   SPI: sample MOSI
        #   JTAG2SPI (BSCAN primitive): sample MISO -> set TDO
        # 3 (rising TCK, falling CLK):
        #   JTAG adapter: sample TDO
        self.fsm.act("IDLE",
                     mg.If(self.jtag.tdi & self.jtag.sel & self.jtag.shift,
                           mg.NextState("HEAD")
                           )
                     )
        self.fsm.act("HEAD",
                     mg.If(head == 0,
                           mg.NextState("XFER")
                           )
                     )
        self.fsm.act("XFER",
                     mg.If(bits == 0,
                           mg.NextState("IDLE")
                           ),
                     )
        self.sync += [
            self.mosi.o.eq(self.jtag.tdi),
            self.cs_n.o.eq(~self.fsm.ongoing("XFER")),
            mg.If(self.fsm.ongoing("HEAD"),
                  bits.eq(mg.Cat(self.jtag.tdi, bits)),
                  head.eq(head - 1)
                  ),
            mg.If(self.fsm.ongoing("XFER"),
                  bits.eq(bits - 1)
                  )
        ]


class JTAG2SPITest(unittest.TestCase):
    def setUp(self):
        self.bits = 8
        self.dut = JTAG2SPI(bits=self.bits)

    def test_instantiate(self):
        pass

    def test_initial_conditions(self):
        def check():
            yield
            self.assertEqual((yield self.dut.cs_n.oe), 0)
            self.assertEqual((yield self.dut.mosi.oe), 0)
            self.assertEqual((yield self.dut.miso.oe), 0)
            self.assertEqual((yield self.dut.clk.oe), 0)
        mg.run_simulation(self.dut, check())

    def test_enable(self):
        def check():
            yield self.dut.jtag.sel.eq(1)
            yield self.dut.jtag.shift.eq(1)
            yield
            self.assertEqual((yield self.dut.cs_n.oe), 1)
            self.assertEqual((yield self.dut.mosi.oe), 1)
            self.assertEqual((yield self.dut.miso.oe), 0)
            self.assertEqual((yield self.dut.clk.oe), 1)
        mg.run_simulation(self.dut, check())

    def run_seq(self, tdi, tdo, spi=None):
        yield self.dut.jtag.sel.eq(1)
        yield
        yield self.dut.jtag.shift.eq(1)
        for di in tdi:
            yield self.dut.jtag.tdi.eq(di)
            yield
            tdo.append((yield self.dut.jtag.tdo))
            if spi is not None:
                v = []
                for k in "cs_n clk mosi miso".split():
                    t = getattr(self.dut, k)
                    v.append("{}>".format((yield t.o)) if (yield t.oe)
                             else "<{}".format((yield t.i)))
                spi.append(" ".join(v))
        yield self.dut.jtag.sel.eq(0)
        yield
        yield self.dut.jtag.shift.eq(0)
        yield

    def test_shift(self):
        bits = 8
        data = 0x81
        tdi = [0, 0, 1]  # dummy from BYPASS TAPs and marker
        tdi += [((bits - 1) >> j) & 1 for j in range(self.bits - 1, -1, -1)]
        tdi += [(data >> j) & 1 for j in range(bits)]
        tdi += [0, 0, 0, 0]  # dummy from BYPASS TAPs
        tdo = []
        spi = []
        mg.run_simulation(self.dut, self.run_seq(tdi, tdo, spi))
        # print(tdo)
        for l in spi:
            print(l)


class Spartan3(mg.Module):
    macro = "BSCAN_SPARTAN3"
    toolchain = "ise"

    def __init__(self, platform):
        platform.toolchain.bitgen_opt += " -g compress -g UnusedPin:Pullup"
        self.submodules.j2s = j2s = JTAG2SPI(platform.request("spiflash"))
        self.specials += [
            mg.Instance(
                self.macro,
                o_SHIFT=j2s.jtag.shift, o_SEL1=j2s.jtag.sel,
                o_CAPTURE=j2s.jtag.capture,
                o_DRCK1=j2s.jtag.tck,
                o_TDI=j2s.jtag.tdi, i_TDO1=j2s.jtag.tdo,
                i_TDO2=0),
        ]
        platform.add_period_constraint(j2s.jtag.tck, 6)


class Spartan3A(Spartan3):
    macro = "BSCAN_SPARTAN3A"


class Spartan6(mg.Module):
    toolchain = "ise"

    def __init__(self, platform):
        platform.toolchain.bitgen_opt += " -g compress -g UnusedPin:Pullup"
        self.submodules.j2s = j2s = JTAG2SPI(platform.request("spiflash"))
        # clk = mg.Signal()
        self.specials += [
            mg.Instance(
                "BSCAN_SPARTAN6", p_JTAG_CHAIN=1,
                o_SHIFT=j2s.jtag.shift, o_SEL=j2s.jtag.sel,
                o_CAPTURE=j2s.jtag.capture,
                o_DRCK=j2s.jtag.tck,
                o_TDI=j2s.jtag.tdi, i_TDO=j2s.jtag.tdo),
            # mg.Instance("BUFG", i_I=clk, o_O=j2s.jtag.tck)
        ]
        platform.add_period_constraint(j2s.jtag.tck, 6)


class Series7(mg.Module):
    toolchain = "vivado"

    def __init__(self, platform):
        platform.toolchain.bitstream_commands.extend([
            "set_property BITSTREAM.GENERAL.COMPRESS True [current_design]",
            "set_property BITSTREAM.CONFIG.UNUSEDPIN Pullnone [current_design]"
        ])
        self.submodules.j2s = j2s = JTAG2SPI(platform.request("spiflash"))
        # clk = mg.Signal()
        self.specials += [
            mg.Instance(
                "BSCANE2", p_JTAG_CHAIN=1,
                o_SHIFT=j2s.jtag.shift, o_SEL=j2s.jtag.sel,
                o_CAPTURE=j2s.jtag.capture,
                o_DRCK=j2s.jtag.tck,
                o_TDI=j2s.jtag.tdi, i_TDO=j2s.jtag.tdo),
            mg.Instance(
                "STARTUPE2", i_CLK=0, i_GSR=0, i_GTS=0,
                i_KEYCLEARB=0, i_PACK=1,
                i_USRCCLKO=j2s.clk.o, i_USRCCLKTS=~j2s.clk.oe,
                i_USRDONEO=1, i_USRDONETS=1),
            # mg.Instance("BUFG", i_I=clk, o_O=j2s.jtag.tck)
        ]
        platform.add_period_constraint(j2s.jtag.tck, 6)
        try:
            self.comb += [
                platform.request("user_sma_gpio_p").eq(j2s.cs_n.i),
                platform.request("user_sma_gpio_n").eq(j2s.clk.o),
                platform.request("user_sma_clock_p").eq(j2s.mosi.o),
                platform.request("user_sma_clock_n").eq(j2s.miso.i),
            ]
        except mb.ConstraintError:
            pass


class Ultrascale(mg.Module):
    toolchain = "vivado"

    def __init__(self, platform):
        platform.toolchain.bitstream_commands.extend([
            "set_property BITSTREAM.GENERAL.COMPRESS True [current_design]",
            "set_property BITSTREAM.CONFIG.UNUSEDPIN Pullnone [current_design]",
        ])
        self.submodules.j2s0 = j2s0 = JTAG2SPI()
        self.submodules.j2s1 = j2s1 = JTAG2SPI(platform.request("spiflash"))
        di = mg.Signal(4)
        self.comb += mg.Cat(j2s0.mosi.i, j2s0.miso.i).eq(di)
        self.specials += [
            mg.Instance("BSCANE2", p_JTAG_CHAIN=1,
                        o_SHIFT=j2s0.jtag.shift, o_SEL=j2s0.jtag.sel,
                        o_CAPTURE=j2s0.jtag.capture,
                        o_DRCK=j2s0.jtag.tck,
                        o_TDI=j2s0.jtag.tdi, i_TDO=j2s0.jtag.tdo),
            mg.Instance("BSCANE2", p_JTAG_CHAIN=2,
                        o_SHIFT=j2s1.jtag.shift, o_SEL=j2s1.jtag.sel,
                        o_CAPTURE=j2s1.jtag.capture,
                        o_DRCK=j2s1.jtag.tck,
                        o_TDI=j2s1.jtag.tdi, i_TDO=j2s1.jtag.tdo),
            mg.Instance("STARTUPE3", i_GSR=0, i_GTS=0,
                        i_KEYCLEARB=0, i_PACK=1,
                        i_USRDONEO=1, i_USRDONETS=1,
                        i_USRCCLKO=mg.Mux(j2s0.clk.oe, j2s0.clk.o, j2s1.clk.o),
                        i_USRCCLKTS=~(j2s0.clk.oe | j2s1.clk.oe),
                        i_FCSBO=j2s0.cs_n.o, i_FCSBTS=~j2s0.cs_n.oe,
                        o_DI=di,
                        i_DO=mg.Cat(j2s0.mosi.o, j2s0.miso.o, 0, 0),
                        i_DTS=mg.Cat(~j2s0.mosi.oe, ~j2s0.miso.oe, 1, 1))
        ]
        platform.add_period_constraint(j2s0.jtag.tck, 6)
        platform.add_period_constraint(j2s1.jtag.tck, 6)


class XilinxBscanSpi(xilinx.XilinxPlatform):
    packages = {
        # (package-speedgrade, id): [cs_n, clk, mosi, miso, *pullups]
        ("ftgb196-1", 1): ["C11", None, "B11", "B12", "D10", "C10"],
        # ("csga225-1", 1): ["L11", None, "H14", "H15", "J12", "K13"],
    }

    pinouts = {
        # bitstreams are named by die, package does not matter, speed grade
        # should not matter.
        #
        # chip: (package, id, standard, class)
        "xc7s25": ("ftgb196-1", 1, "LVCMOS33", Series7),
    }

    def __init__(self, device, pins, std, toolchain="ise"):
        ios = [self.make_spi(0, pins, std, toolchain)]
        if device == "xc7k325t-ffg900-1":  # debug
            ios += [
                ("user_sma_clock_p", 0, mb.Pins("L25"), mb.IOStandard("LVCMOS25")),
                ("user_sma_clock_n", 0, mb.Pins("K25"), mb.IOStandard("LVCMOS25")),
                ("user_sma_gpio_p", 0, mb.Pins("Y23"), mb.IOStandard("LVCMOS25")),
                ("user_sma_gpio_n", 0, mb.Pins("Y24"), mb.IOStandard("LVCMOS25")),
            ]
        xilinx.XilinxPlatform.__init__(self, device, ios, toolchain=toolchain)

    @staticmethod
    def make_spi(i, pins, std, toolchain):
        pu = "PULLUP" if toolchain == "ise" else "PULLUP TRUE"
        pd = "PULLDOWN" if toolchain == "ise" else "PULLDOWN TRUE"
        cs_n, clk, mosi, miso = pins[:4]
        io = ["spiflash", i,
              mb.Subsignal("cs_n", mb.Pins(cs_n), mb.Misc(pu)),
              mb.Subsignal("mosi", mb.Pins(mosi), mb.Misc(pu)),
              mb.Subsignal("miso", mb.Pins(miso), mb.Misc(pu)),
              mb.IOStandard(std),
              ]
        if clk:
            io.append(mb.Subsignal("clk", mb.Pins(clk), mb.Misc(pd)))
        for i, p in enumerate(pins[4:]):
            io.append(mb.Subsignal("pullup{}".format(i), mb.Pins(p),
                                   mb.Misc(pu)))
        return io

    @classmethod
    def make(cls, target, errors=False):
        pkg, id, std, Top = cls.pinouts[target]
        pins = cls.packages[(pkg, id)]
        device = target.split("-", 1)[0]
        platform = cls("{}-{}".format(device, pkg), pins, std, Top.toolchain)
        top = Top(platform)
        name = "bscan_spi_{}".format(target)
        try:
            platform.build(top, build_name=name)
        except Exception as e:
            print(("ERROR: xilinx_bscan_spi build failed "
                   "for {}: {}").format(target, e))
            if errors:
                raise


if __name__ == "__main__":
    import argparse
    import multiprocessing
    p = argparse.ArgumentParser(description="build bscan_spi bitstreams "
                                "for openocd jtagspi flash driver")
    p.add_argument("device", nargs="*",
                   default=sorted(list(XilinxBscanSpi.pinouts)),
                   help="build for these devices (default: %(default)s)")
    p.add_argument("-p", "--parallel", default=1, type=int,
                   help="number of parallel builds (default: %(default)s)")
    args = p.parse_args()
    pool = multiprocessing.Pool(args.parallel)
    pool.map(XilinxBscanSpi.make, args.device, chunksize=1)

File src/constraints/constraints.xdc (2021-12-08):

## 12 MHz System Clock
set_property -dict {PACKAGE_PIN H3 IOSTANDARD LVCMOS33} [get_ports clk]
create_clock -period 83.330 -name sys_clk_pin -waveform {0.000 41.660} -add [get_ports clk]

## Because system clock is not on the correct pin
set_property CLOCK_DEDICATED_ROUTE FALSE [get_nets clk_IBUF]

## USB UART
## Note: Port names are from the perspoctive of the FPGA.
set_property -dict { PACKAGE_PIN F1   IOSTANDARD LVCMOS33 } [get_ports { uart_tx }]
set_property -dict { PACKAGE_PIN G1   IOSTANDARD LVCMOS33 } [get_ports { uart_rx }]

## Cartridge ports
set_property -dict { PACKAGE_PIN P10   IOSTANDARD LVCMOS33 } [get_ports { gb_clk }]
set_property -dict { PACKAGE_PIN N10   IOSTANDARD LVCMOS33 } [get_ports { gb_wr }]
set_property -dict { PACKAGE_PIN P11   IOSTANDARD LVCMOS33 } [get_ports { gb_rd }]
set_property -dict { PACKAGE_PIN N11   IOSTANDARD LVCMOS33 } [get_ports { gb_cs }]
set_property -dict { PACKAGE_PIN P12   IOSTANDARD LVCMOS33 } [get_ports { gb_a[0] }]
set_property -dict { PACKAGE_PIN M12   IOSTANDARD LVCMOS33 } [get_ports { gb_a[1] }]
set_property -dict { PACKAGE_PIN P13   IOSTANDARD LVCMOS33 } [get_ports { gb_a[2] }]
set_property -dict { PACKAGE_PIN N14   IOSTANDARD LVCMOS33 } [get_ports { gb_a[3] }]
set_property -dict { PACKAGE_PIN M13   IOSTANDARD LVCMOS33 } [get_ports { gb_a[4] }]
set_property -dict { PACKAGE_PIN M14   IOSTANDARD LVCMOS33 } [get_ports { gb_a[5] }]
set_property -dict { PACKAGE_PIN L13   IOSTANDARD LVCMOS33 } [get_ports { gb_a[6] }]
set_property -dict { PACKAGE_PIN L14   IOSTANDARD LVCMOS33 } [get_ports { gb_a[7] }]
set_property -dict { PACKAGE_PIN J13   IOSTANDARD LVCMOS33 } [get_ports { gb_a[8] }]
set_property -dict { PACKAGE_PIN J14   IOSTANDARD LVCMOS33 } [get_ports { gb_a[9] }]
set_property -dict { PACKAGE_PIN H13   IOSTANDARD LVCMOS33 } [get_ports { gb_a[10] }]
set_property -dict { PACKAGE_PIN H14   IOSTANDARD LVCMOS33 } [get_ports { gb_a[11] }]
set_property -dict { PACKAGE_PIN G14   IOSTANDARD LVCMOS33 } [get_ports { gb_a[12] }]
set_property -dict { PACKAGE_PIN F14   IOSTANDARD LVCMOS33 } [get_ports { gb_a[13] }]
set_property -dict { PACKAGE_PIN F13   IOSTANDARD LVCMOS33 } [get_ports { gb_a[14] }]
set_property -dict { PACKAGE_PIN E13   IOSTANDARD LVCMOS33 } [get_ports { gb_a[15] }]
set_property -dict { PACKAGE_PIN D14   IOSTANDARD LVCMOS33 } [get_ports { gb_rst }]
set_property -dict { PACKAGE_PIN D13   IOSTANDARD LVCMOS33 } [get_ports { gb_d[0] }]
set_property -dict { PACKAGE_PIN C14   IOSTANDARD LVCMOS33 } [get_ports { gb_d[1] }]
set_property -dict { PACKAGE_PIN D12   IOSTANDARD LVCMOS33 } [get_ports { gb_d[2] }]
set_property -dict { PACKAGE_PIN B14   IOSTANDARD LVCMOS33 } [get_ports { gb_d[3] }]
set_property -dict { PACKAGE_PIN B13   IOSTANDARD LVCMOS33 } [get_ports { gb_d[4] }]
set_property -dict { PACKAGE_PIN C12   IOSTANDARD LVCMOS33 } [get_ports { gb_d[5] }]
set_property -dict { PACKAGE_PIN A13   IOSTANDARD LVCMOS33 } [get_ports { gb_d[6] }]
set_property -dict { PACKAGE_PIN A12   IOSTANDARD LVCMOS33 } [get_ports { gb_d[7] }]
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

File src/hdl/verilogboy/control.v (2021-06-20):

`timescale 1ns / 1ns
`default_nettype wire
`include "common.v"
//////////////////////////////////////////////////////////////////////////////////
// Company:
// Engineer: Wenting Zhang
//
// Module Name:    control
// Project Name:   VerilogBoy
// Description:
//   The control unit of Game Boy CPU.
// Dependencies:
//
// Additional Comments:
//
//////////////////////////////////////////////////////////////////////////////////

module control(
    input        clk,
    input        rst,
    input  [7:0] opcode_early,
    /* verilator lint_off UNUSED */
    input  [7:0] imm,
    /* verilator lint_on UNUSED */
    input  [7:0] cb,
    input  [2:0] m_cycle_early,
    input  [1:0] ct_state,
    input        f_z,
    input        f_c,
    output reg [1:0] alu_src_a,
    output reg [2:0] alu_src_b,
    output reg       alu_src_xchg,
    output reg [1:0] alu_op_prefix,
    output reg [1:0] alu_op_src,
    output reg       alu_op_signed,
    output reg [1:0] alu_dst,
    output reg [1:0] pc_src,
    output reg       pc_we,
    output reg       pc_b_sel,
    output reg       pc_jr,
    output reg       pc_revert,
    output reg [2:0] rf_wr_sel,
    output reg [2:0] rf_rd_sel,
    output reg [1:0] rf_rdw_sel,
    output reg       temp_redir,
    output reg       opcode_redir,
    output reg [1:0] bus_op,
    output reg [1:0] db_src,
    output reg [1:0] ab_src,
    output reg [1:0] ct_op,
    output reg       flags_we,
    output reg [1:0] flags_pattern,
    output reg       high_mask,
    output           int_master_en,
    input            int_dispatch,
    output reg       int_ack,
    output reg       next,
    output reg       stop,
    output reg       halt,
    input            wake,
    output reg       fault
    );

    // Comb signal generated by control logic
    reg ime_clear;
    reg ime_set;
    reg ime_delay_set;
    // FF
    reg ime_delay_set_ff;
    reg ime;
    assign int_master_en = ime;

    wire [7:0] opcode = opcode_early;
    wire [2:0] m_cycle = m_cycle_early;

    always @(posedge clk)
        if (ct_state == 2'd2)
            ime_delay_set_ff <= ime_delay_set;

    always @(posedge clk) begin
        if (rst)
            ime <= 1'b0;
        else if (ime_clear)
            ime <= 1'b0;
        else if (ime_set)
            ime <= 1'b1;
        else if (ime_delay_set_ff)
            ime <= 1'b1;
    end

    reg halt_last;
    reg stop_last;
    reg fault_last;
    always @(posedge clk) begin
        if (rst) begin
            halt_last <= 1'b0;
            stop_last <= 1'b0;
            fault_last <= 1'b0;
        end
        else begin
            halt_last <= halt;
            stop_last <= stop;
            fault_last <= fault;
        end
    end

    reg wake_by_int;
    always @(posedge clk) begin
        if (rst)
            wake_by_int <= 1'b0;
        else begin
            if (int_dispatch && (m_cycle == 0)) begin
                wake_by_int <= wake;
            end
        end
    end

    // Combinational control signal
    reg [1:0] comb_alu_src_a;
    reg [2:0] comb_alu_src_b;
    reg       comb_alu_src_xchg;
    reg [1:0] comb_alu_op_prefix;
    reg [1:0] comb_alu_op_src;
    reg       comb_alu_op_signed;
    reg [1:0] comb_alu_dst;
    reg [1:0] comb_pc_src;
    reg       comb_pc_we;
    reg       comb_pc_b_sel;
    reg       comb_pc_jr;
    reg       comb_pc_revert;
    reg [2:0] comb_rf_wr_sel;
    reg [2:0] comb_rf_rd_sel;
    reg [1:0] comb_rf_rdw_sel;
    reg       comb_temp_redir;
    reg       comb_opcode_redir;
    reg [1:0] comb_bus_op;
    reg [1:0] comb_db_src;
    reg [1:0] comb_ab_src;
    reg [1:0] comb_ct_op;
    reg       comb_flags_we;
    reg [1:0] comb_flags_pattern;
    reg       comb_high_mask;
    reg       comb_int_ack;
    reg       comb_next;
    reg       comb_stop;
    reg       comb_halt;
    reg       comb_fault;
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

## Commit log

2021-06-21 Assign footprint and place fpga on board
    [gb-fpga.kicad_pcb, gb-fpga.sch]
2021-06-21 Basic boards setup
    [gb-fpga.kicad_pcb]
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2021-06-22 Add hierarchical sheets
    [banks.sch, configuration.sch, gb-fpga.sch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]
2021-06-22 Add GND net
    [configuration.sch, gb-fpga.kicad_pcb, power.sch]
2021-06-22 Use USON footprint for flash memory
    [configuration.sch, gb-fpga.kicad_pcb]
2021-06-22 Use human readable names on pcb
    [gb-fpga.kicad_pcb]
2021-06-23 Add board outline
    [gb-fpga.kicad_pcb]
2021-06-23 Move board origin to 0 0
    [gb-fpga.kicad_pcb]
2021-06-23 Add second mounting hole
    [gb-fpga.kicad_pcb]
2021-06-23 Add usb parts
    [banks.sch, configuration.sch, gb-fpga.kicad_pcb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]
2021-06-23 Add additional mounting holes
    [gb-fpga.kicad_pcb]
2021-06-23 Changes to pcb file
    [gb-fpga.kicad_pcb]
2021-06-23 Add and place cartridge footprint and place usb connector
    [banks.sch, cartridge.sch, configuration.sch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]
2021-06-24 Add mounting holes to cartridge footprint
    [gb-fpga.kicad_pcb]
2021-06-24 Rename cartridge symbol
    [cartridge.sch, gb-fpga.kicad_pcb]
2021-06-24 Add connections to flash ic
    [configuration.sch, gb-fpga.kicad_pcb]
2021-06-24 Add local fpga symbol
    [cartridge.sch, gb-fpga.csv, gb-fpga.kicad_pcb]
2021-06-24 Connect flash config circuit
    [banks.sch, configuration.sch, gb-fpga.kicad_pcb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]
2021-06-25 Replace micro usb with usb type c connector
    [gb-fpga.kicad_pcb, usb.sch]
2021-06-25 Update flash footprint
    [gb-fpga.kicad_pcb]
2021-06-25 Add USB connections
    [banks.sch, configuration.sch, gb-fpga.kicad_pcb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]
2021-06-26 Add oscillator
    [banks.sch, gb-fpga.kicad_pcb, usb.sch]
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2021-06-27 Add reverse polarity protection to usb
    [gb-fpga.kicad_pcb, usb.sch]
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2021-06-27 Use power up sequence recommended for Spartan FPGA
    [gb-fpga.kicad_pcb, power.sch]
2021-06-28 Switch from 0603 to 0402 footprints
    [configuration.sch, gb-fpga.kicad_pcb, power.sch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]
2021-06-28 Add chargeing indicator LED
    [configuration.sch, gb-fpga.kicad_pcb, power.sch]
2021-06-28 Add 5V voltage regulator
    [gb-fpga.kicad_pcb, power.sch]
2021-06-29 Add capacitor networks to fpga power rails
    [gb-fpga.kicad_pcb, power-fpga.sch]
2021-06-30 Hook up cartridge to translation ics
    [cartridge.sch, gb-fpga.kicad_pcb]
2021-07-01 Fix cartridge pin out and replace voltage translators
    [cartridge.sch, gb-fpga.csv, gb-fpga.kicad_pcb]
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2021-07-01 Add signals to board connector
    [board-connector.sch, gb-fpga.kicad_pcb]
2021-07-02 Add audio filter and volume control to schematic
    [board-connector.sch]
2021-07-02 Add missing power supplies
    [cartridge.sch, gb-fpga.kicad_pcb, usb.sch]
2021-07-02 Add volume control footprint
    [board-connector.sch, gb-fpga.kicad_pcb]
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2021-07-03 Fix volume control pinout
    [gb-fpga.kicad_pcb]
2021-07-03 Fix moved edge cut
    [gb-fpga.kicad_pcb]
2021-07-03 Increase edge cut thickness to increase edge clearance
    [gb-fpga.kicad_pcb]
2021-07-03 Layout some smaller groups
    [gb-fpga.kicad_pcb]
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2021-07-04 Fan out part of BGA
    [gb-fpga.kicad_pcb]
2021-07-04 Fan out cartridge pins
    [gb-fpga.kicad_pcb]
2021-07-04 Switch to 0201 footprints for fpga power caps
    [gb-fpga.kicad_pcb, power-fpga.sch]
2021-07-04 Place most fpga caps
    [gb-fpga.kicad_pcb]
2021-07-04 Assign cartridge pins to fpga
    [banks.sch, gb-fpga.kicad_pcb]
2021-07-04 Fan out board connector pins
    [gb-fpga.kicad_pcb]
2021-07-04 Assign board connector pins to fpga
    [banks.sch, board-connector.sch, gb-fpga.kicad_pcb]
2021-07-04 Fan out the remaining pins
    [banks.sch, gb-fpga.kicad_pcb]
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2021-07-05 Add some more power zones
    [gb-fpga.kicad_pcb]
2021-07-05 Add more tracks and regions
    [gb-fpga.kicad_pcb]
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2021-07-06 Route all power rails
    [gb-fpga.kicad_pcb]
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2021-07-06 Place remaining cap arrays and fix missing connections
    [gb-fpga.kicad_pcb]
2021-07-06 Update silkscreen and plit gerbers
    [gb-fpga-B_Cu.gbr, gb-fpga-B_Mask.gbr, gb-fpga-B_Paste.gbr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]
2021-07-06 Add logo and revision
    [gb-fpga-B_Cu.gbr, gb-fpga-B_Mask.gbr, gb-fpga-B_Paste.gbr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]
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2021-07-07 Add test points and update gerber for pcb way
    [banks.sch, board-connector.sch, cartridge.sch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]
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2021-07-08 Update footprints and BOM
    [gb-fpga-B_Cu.gbl, gb-fpga-B_Mask.gbs, gb-fpga-B_Paste.gbp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]
2021-07-08 Add bom and centroid file
    [bom.csv, centroid.csv]
2021-07-09 Fix connection on U4
    [gb-fpga-B_Cu.gbl, gb-fpga-B_Mask.gbs, gb-fpga-B_Paste.gbp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]
2021-07-09 Increase min drill size to 0.3mm
    [gb-fpga-B_Cu.gbl, gb-fpga-B_Mask.gbs, gb-fpga-B_Paste.gbp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]
2021-07-09 Update BOM with substitute for flash memory
    [bom.csv, configuration.sch]
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2021-07-24 Init empty kicad project for hi board
    [hi-board.kicad_pcb, hi-board.sch]
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2021-08-21 Add hardware config files
    [fpgamb0.cfg]
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2021-08-26 Update bitstream programming config
    [fpgamb0.cfg]
2021-08-27 Improve openocd config file
    [fpgamb0.cfg]
2021-08-27 Add flash programming config (not working as of now)
    [fpgamb0.cfg, prog-flash.cfg, prog-fpga.cfg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]
2021-08-29 Update openocd config for openocd 0.11
    [prog-flash.cfg, prog-fpga.cfg]
2021-09-04 Update some board specific params and files
    [prog-flash.cfg, prog-fpga.cfg]
2021-09-04 Update HI board files
    [hi-board.sch]
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2021-09-15 Add display and power supply to schematics
    [audio.sch, board-connector.sch, display.sch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]
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2021-09-17 Add potentiometer to display schematic
    [display.sch]
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2021-09-19 Complete display schematic and change footprints
    [audio.sch, display.sch, joypad.sch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]
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2021-09-23 Add HI board outline
    [hi-board.kicad_pcb]
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2021-10-08 Add joypad footprints to layout
    [hi-board.kicad_pcb]
2021-10-09 Flip mounting holes to bottom side
    [hi-board.kicad_pcb]
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2021-10-09 Update audio circuit to SMD only
    [audio.sch, hi-board.kicad_pcb]
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2021-10-12 Place remaining fix components
    [hi-board.kicad_pcb]
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2021-10-13 Route all but power rails
    [hi-board.kicad_pcb]
2021-10-13 Complete routing of HI board
    [hi-board.kicad_pcb]
2021-10-13 Add logo and rev
    [hi-board.kicad_pcb]
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2021-10-27 Fix missing connection on hi board
    [hi-board.kicad_pcb]
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2021-11-06 Fix SPI pin configuration
    [constraints.xdc]
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2021-11-12 Fix data bus wiring
2021-11-13 Fix rgb wiring and switch to proper grayscale output
    [constraints.xdc]
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2021-12-08 Fix PPU bug where PPU is supposed to enter mode 0 on disable
    [ppu.v]

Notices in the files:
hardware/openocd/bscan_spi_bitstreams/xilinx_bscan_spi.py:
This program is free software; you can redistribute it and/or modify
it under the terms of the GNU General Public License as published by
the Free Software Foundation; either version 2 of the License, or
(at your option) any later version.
